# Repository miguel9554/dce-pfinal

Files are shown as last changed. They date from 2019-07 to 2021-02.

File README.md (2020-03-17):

# repositorio del proyecto final de dce - 1c2019

integrantes:

- Juan Ciafardini, 97921
- Miguel Perez Andrade, 98599
- Luis Tomás Quiroga, 96337

# 19/12/2019

## 18:00, primera medición

Medimos el punto de operación del amplificador diferencial y la fuente de corriente

* V_R10 [mV]:   571.2
* V_R8  [mV]:   383.8 
* V_R7  [mV]:   5.2
* V_R6  [mV]:   377.7
* V_R2  [mV]:   99
* V_R1  [mV]:   57.3
* V_bQ2 [mV]:   631
* V_bQ3 [mV]:   202.1

Problemas:

* Falta una vía en el emisor de Q2          -> corregido
* Un cacho de tierra no está conectado      -> conecta nada más las resistencias de la etapa de potencia, después lo conectamos
* Se rompio el contacto del capa C3         -> arreglar cuando se mida la señal

## 19:28, segunda medición

Medimos el punto de operación del amplificador diferencial y la fuente de corriente

* V_R10 [mV]:   568.1
* V_R8  [mV]:   380.7 
* V_R7  [mV]:   5.2
* V_R6  [mV]:   374.5
* V_R2  [mV]:   98.1
* V_R1  [mV]:   156.4
* V_bQ2 [mV]:   628
* V_eQ2 [V]:    -9.97
* V_bQ3 [mV]:   200.1
* V_eQ3  [V]:   -9.29

Cálculos

* I_R7  :   0.052u
* I_R6  :   3.74m
* I_R2  :   1.44m
* I_R1  :   2.3m
* I_R15 :   52u
* I_R5  :   16.67u

# 03/02/2020

## 16:40, 1ra medición

Medimos el punto de operación del amplificador diferencial y la fuente de corriente (nodos diff LT)

* V_R10 [mV]:   573.2           (J9 vs V+)
* V_R8  [mV]:   387.5           (J4 vs V+)
* V_R7  [mV]:   5.3         (entre J19 y J2)
* V_R6  [mV]:   378.4           (entre J19 y J20)
* V_R2  [mV]:   99.8            (J3 vs V-)
* V_R1  [mV]:   157.2           (J6 vs V-, entrada)
* V_bQ2 [mV]:   604.7           (J15)
* V_eQ2 [V]:    1.175
* V_bQ3 [mV]:   200.8
* V_eQ3  [V]:   0.806

Soldamos los conectores de Q2 y Q4 que estaban desconectados, medimos de vuelta

## 17:37, 2da medición

Medimos el punto de operación del amplificador diferencial y la fuente de corriente (nodos diff LT)

* V_R10 [mV]:   571.1               (J9 vs V+)
* V_R8  [mV]:   383.5               (J4 vs V+)
* V_R7  [mV]:   190.8               (entre J19 y J2)
* V_R6  [mV]:   191.1               (entre J19 y J20)
* V_R2  [mV]:   130.9               (J3 vs V-)
* V_R1  [mV]:   129.0               (J6 vs V-, entrada)
* V_bQ2 [mV]:   102.3               (J15)
* V_eQ2 [mV]:   696.0
* V_bQ3 [mV]:   103.0
* V_eQ3 [mV]:   696.0

Soldamos R10 a V+, y el capa de filtrado de la fuente de corriente (C7 en Kicad) a V+

## 18:32, 3ra medición

Medimos el punto de operación del amplificador diferencial y la fuente de corriente (nodos diff LT)

* V_R10 [mV]:   563.5               (J9 vs V+)
* V_R8  [mV]:   538.5               (J4 vs V+)
* V_R7  [mV]:   267.4               (entre J19 y J2)
* V_R6  [mV]:   267.3               (entre J19 y J20)
* V_R2  [mV]:   183.0               (J3 vs V-)
* V_R1  [mV]:   180.0               (J6 vs V-, entrada)
* V_bQ2 [mV]:   141.8               (J15)
* V_eQ2 [mV]:   742.0
* V_bQ3 [mV]:   143.2
* V_eQ3 [mV]:   742.0

Cambiamos la resistencia R8 por una de 47, era de 100 y estaba dando mal por eso

## 19:14, 4ta medición

Medimos el punto de operación del amplificador diferencial y la fuente de corriente (nodos diff LT)

* V_R10 [mV]:   561.6               (J9 vs V+)
* V_R8  [mV]:   497.8               (J4 vs V+)
* V_R7  [mV]:   528.9               (entre J19 y J2)
* V_R6  [mV]:   529.4               (entre J19 y J20)
* V_R2  [mV]:   361.8               (J3 vs V-)
* V_R1  [mV]:   357.5               (J6 vs V-, entrada)
* V_bQ2 [mV]:   274.3               (J15)
* V_eQ2 [mV]:   880.0
* V_bQ3 [mV]:   275.5
* V_eQ3 [mV]:   879.0

Medimos con 30V GUARDA CON LAS CHISPAS

## 19:21, 5ta medición

Medimos el punto de operación del amplificador diferencial y la fuente de corriente (nodos diff LT)

* V_R10 [mV]:   582.7               (J9 vs V+)
* V_R8  [mV]:   548.5               (J4 vs V+)
* V_R7  [mV]:   583.3               (entre J19 y J2)
* V_R6  [mV]:   581.7               (entre J19 y J20)
* V_R2  [mV]:   399.1               (J3 vs V-)
* V_R1  [mV]:   392.9               (J6 vs V-, entrada)
* V_bQ2 [mV]:   245.1               (J15)
* V_eQ2 [mV]:   795.0
* V_bQ3 [mV]:   245.7
* V_eQ3 [mV]:   796.0

# 04/02/2020

## 17:42, 1ra medición

Medimos después de soldar el vas sin conectarlo todavía, para ver que todo siga andando

* V_R10 [mV]:   564.2           (J9 vs V+)
* V_R8  [mV]:   497.2           (J4 vs V+)
* V_R7  [mV]:   527.4           (entre J19 y J2)
* V_R6  [mV]:   527.1           (entre J19 y J20)
* V_R2  [mV]:   360.7           (J3 vs V-)
* V_R1  [mV]:   356.0           (J6 vs V-, entrada)
* V_bQ2 [mV]:   274.0           (J15)
* V_eQ2 [mV]:   883.0
* V_bQ3 [mV]:   276.3
* V_eQ3 [mV]:   883.0

## 18:00, 2da medición

Medimos con todo conectado (vas)

* V_R10 [mV]:   32          (J9 vs V+)
* V_R8  [mV]:   58.9            (J4 vs V+)
* V_R7  [mV]:   93.9        (entre J19 y J2)
* V_R6  [mV]:   30.4            (entre J19 y J20)
* V_R2  [mV]:   21.8            (J3 vs V-)
* V_R1  [mV]:   20.3            (J6 vs V-, entrada)
* V_bQ2 [mV]:   7670            (J15)
* V_eQ2 [mV]:   8390
* V_bQ3 [mV]:   7860
* V_eQ3 [mV]:   8460
* V_Vas [mv]:   7980

## 18:26, 3ra medición

Arreglamos la pista que se había cortado (la que iba entre la salida del vas y el diodo) y dimos vuelta los diodos

* V_R10 [mV]:   32          (J9 vs V+)
* V_R8  [mV]:   58.9            (J4 vs V+)
* V_R7  [mV]:   93.9        (entre J19 y J2)
* V_R6  [mV]:   30.4            (entre J19 y J20)
* V_R2  [mV]:   21.8            (J3 vs V-)
* V_R1  [mV]:   20.3            (J6 vs V-, entrada)
* V_bQ2 [mV]:   7670            (J15)
* V_eQ2 [mV]:   8390
* V_bQ3 [mV]:   7860
* V_eQ3 [mV]:   8460
* V_Vas [mv]:   7980

## 19:09, 4ta medición

No estaba conectado el jumper que conectaba la salida del diferencial con el buffer, lo soldamos. También soldamos una pata del transitor del mult de vbe.

* Vcc   [V]:    10   |  30
* V_R10 [mV]:   560.2|580.0             (J9 vs V+)
* V_R8  [mV]:   502.9|567.0             (J4 vs V+)
* V_R7  [mV]:   534.4|602.0             (entre J19 y J2)
* V_R6  [mV]:   536.3|607.5             (entre J19 y J20)
* V_R2  [mV]:   367.1|413.2             (J3 vs V-)
* V_R1  [mV]:   364.9|411.3             (J6 vs V-, entrada)
* V_bQ2 [mV]:   273.6|248.3             (J15)
* V_eQ2 [mV]:   879.0|794.0
* V_bQ3 [mV]:   268.4|237.7
* V_eQ3 [mV]:   875.0|790.0
* V_Vas [mv]:   016.0|019.0

# 06/02/2020

## 17:21, 1ra medición

Alimentación de 27.6 V

* V_R10 [mV]:   590.8           (J9 vs V+)
* V_R8  [mV]:   599.0           (J4 vs V+)
* V_R7  [mV]:   124.3           (entre J19 y J2)
* V_R6  [mV]:   1042.0          (entre J19 y J20)
* V_R2  [mV]:   446.0           (J3 vs V-)
* V_R1  [mV]:   524.0           (J6 vs V-, entrada)
* V_bQ2 [mV]:   15023.0         (J15)
* V_eQ2 [mV]:   24040.0
* V_bQ3 [mV]:   22038.0
* V_eQ3 [mV]:   23075.0

## 18:23, 2da medición

Medición con la realimentación conectada, no está funcionando

* V_R10 [mV]:   603.5           (J9 vs V+)
* V_R8  [mV]:   600.0           (J4 vs V+)
* V_R7  [mV]:   126.2           (entre J19 y J2)
* V_R6  [mV]:   1430.0          (entre J19 y J20)
* V_R2  [mV]:   448.0           (J3 vs V-)
* V_R1  [mV]:   530.0           (J6 vs V-, entrada)
* V_bQ2 [mV]:   15300.0         (J15)
* V_eQ2 [mV]:   24640.0
* V_bQ3 [mV]:   22440.0
* V_eQ3 [mV]:   24000.0

## 18:31, 3ra medición

Medición solo del diferencial

* V_R10 [mV]:   600.8           (J9 vs V+)
* V_R8  [mV]:   558.0           (J4 vs V+)
* V_R7  [mV]:   569.5           (entre J19 y J2)
* V_R6  [mV]:   617.0           (entre J19 y J20)
* V_R2  [mV]:   404.6           (J3 vs V-)
* V_R1  [mV]:   411.0           (J6 vs V-, entrada)
* V_bQ2 [mV]:   332.0           (J15)
* V_eQ2 [mV]:   898.7
* V_bQ3 [mV]:   281.0
* V_eQ3 [mV]:   846.0

# 10/02/2020

# 16:29, 1ra medición

Como no anduvo una mierda la semana pasada, vamos a medir todos los transistores para ver si alguno está roto. Nos basamos en lo explicado en https://www.fluke.com/en-us/learn/best-practices/test-tools-basics/digital-multimeters/how-to-test-diodes-using-a-digital-multimeter y https://electronics.stackexchange.com/a/83752. Los nombres de los transistores van a estar referidos al esquemático de kicad. Todas las mediciones se hacen con un multimetro en modo diodo

* Q3
    * VbeD [mv]: 646
    * VbeI [mv]: 1800
    * VbcD [mv]: 641
    * VbcI [mv]: 0L
    * Vec [mv]: 0L
    * Vce [mv]: 1343
* Q1
    * VbeD [mv]: 649
    * VbeI [mv]: 0L
    * VbcD [mv]: 645
    * VbcI [mv]: 0L
    * Vec [mv]: 700
    * Vce [mv]: 0L
* Q5
    * VbeD [mv]: 642
    * VbeI [mv]: 0L
    * VbcD [mv]: 639
    * VbcI [mv]: 0L
    * Vec [mv]: 0L
    * Vce [mv]: 0L
* Q2
    * VbeD [mv]: 649
    * VbeI [mv]: 0L
    * VbcD [mv]: 648
    * VbcI [mv]: 0L
    * Vec [mv]: 0L
    * Vce [mv]: 1300

* Q2 (tiene cortado base y colector)
    * VbeD [mv]: 600
    * VbeI [mv]: 0L
    * VbcD [mv]: -
    * VbcI [mv]: -
    * Vec [mv]: -
    * Vce [mv]: -

* Q7
    * VbeD [mv]: 656
    * VbeI [mv]: 0L
    * VbcD [mv]: 651
    * VbcI [mv]: 0L
    * Vec [mv]: 710
    * Vce [mv]: 710

* Q10
    * VbeD [mv]: 655
    * VbeI [mv]: 1415
    * VbcD [mv]: 652
    * VbcI [mv]: 0L
    * Vec [mv]: 911
    * Vce [mv]: 0L

* Q8
    * VbeD [mv]: 645
    * VbeI [mv]: 844
    * VbcD [mv]: 640
    * VbcI [mv]: 0L
    * Vec [mv]: 861
    * Vce [mv]: 1715

* Q6
    * VbeD [mv]: 1403
    * VbeI [mv]: 1430
    * VbcD [mv]: 1722
    * VbcI [mv]: 1723
    * Vec [mv]: 700
    * Vce [mv]: 888

* Q9
    * VbeD [mv]: 589
    * VbeI [mv]: 1040
    * VbcD [mv]: 583
    * VbcI [mv]: 1695
    * Vec [mv]: 1008
    * Vce [mv]: 1799

Medimos un mje340 y un mpsa06 buenos, sin usar

* MJE340
    * VbeD [mv]: 618
    * VbeI [mv]: 0L
    * VbcD [mv]: 613
    * VbcI [mv]: 0L
    * Vec [mv]: 0L
    * Vce [mv]: 0L

* MPSA06
    * VbeD [mv]: 668
    * VbeI [mv]: 0L
    * VbcD [mv]: 665
    * VbcI [mv]: 0L
    * Vec [mv]: 0L
    * Vce [mv]: 0L

Con estás ultimas mediciones, parece que están todos rotos salvo Q5. Es posible que el circuito externo que tiene cada dispositivo esté alterando las mediciones, y los resultados no sean correctos. Vamos a sacar los transistores y medirlos solos para comprobar.

Mediciones con los transistores desoldados:

* Q9
    * VbeD [mv]: 624
    * VbeI [mv]: 0L
    * VbcD [mv]: 620
    * VbcI [mv]: 0L
    * Vec [mv]: 0L
    * Vce [mv]: 0L

* Q3
    * VbeD [mv]: 646
    * VbeI [mv]: 0L
    * VbcD [mv]: 643
    * VbcI [mv]: 0L
    * Vec [mv]: 0L
    * Vce [mv]: 0L

* Q10
    * VbeD [mv]: 661
    * VbeI [mv]: 0L
    * VbcD [mv]: 630
    * VbcI [mv]: 0L
    * Vec [mv]: 0L
    * Vce [mv]: 0L

* Q7 (parece estar cagado, ver la potencia)
    * VbeD [mv]: 653
    * VbeI [mv]: 0L
    * VbcD [mv]: 650
    * VbcI [mv]: 0L
    * Vec [mv]: \~710
    * Vce [mv]: \~710

Con Q9 comprobamos la medición volviendo a soldarlo, y dio mal igual que antes. Esto nos da la pauta de que el circuito externo a cada dispositivo esta perturbando la medición cuando medimos al dispositivo conectado al resto del circuito.

Q7 parece estar cagado, la medición del transistor solo da mal (no hay abierto entre colector y emisor). En base a esto y a que el circuito diferencial estaba funcionando sin la etapa VAS, suponemos que cambiar este transistor va a solucionar el problema.

## 18:52, 2da medición

Medimos con Q7 reemplazado, el circuito diferencial con el vas (medimos rápidamente la fuente de corriente y el diferencial antes de esto y daba bien)
Se quemó la resistencia R4 (en PCB)

* V_R10 [mV]:   573.3           (J9 vs V+)
* V_R8  [mV]:   536.6           (J4 vs V+)
* V_R7  [mV]:   081.5           (entre J19 y J2)
* V_R6  [mV]:   1018.0           (entre J19 y J20)
* V_R2  [mV]:   384.0           (J3 vs V-)
* V_R1  [mV]:   430.5           (J6 vs V-, entrada)
* V_bQ2 [mV]:   -15150          (J15)
* V_eQ2 [mV]:   -18160
* V_bQ3 [mV]:   -14260
* V_eQ3 [mV]:   -19320
* V_oVAS[mV]:   -18750

## 19:07, 2da medición

Medimos solo el diferencial para comprobar que siga andando

* V_R10 [mV]:   599.0           (J9 vs V+)
* V_R8  [mV]:   541.9           (J4 vs V+)
* V_R7  [mV]:   530.8           (entre J19 y J2)
* V_R6  [mV]:   577.9           (entre J19 y J20)
* V_R2  [mV]:   373.6           (J3 vs V-)
* V_R1  [mV]:   378.4           (J6 vs V-, entrada)
* V_bQ2 [mV]:   319.7          (J15)
* V_eQ2 [mV]:   886.6
* V_bQ3 [mV]:   270.4
* V_eQ3 [mV]:   843.4

Vamos a medir los transistores del par diferencial y su carga activa

* Q1
    * VbeD [mv]: 647
    * VbeI [mv]: 0L
    * VbcD [mv]: 643.8
    * VbcI [mv]: 0L
    * Vec [mv]: 0L
    * Vce [mv]: 0L

* Q5
    * VbeD [mv]: 640.0
    * VbeI [mv]: 0L
    * VbcD [mv]: 643.4
    * VbcI [mv]: 0L
    * Vec [mv]: 0L
    * Vce [mv]: 0L

* Q2
    * VbeD [mv]: 668.0
    * VbeI [mv]: 0L
    * VbcD [mv]: 599.5
    * VbcI [mv]: 0L
    * Vec [mv]: 0L
    * Vce [mv]: 0L

* Q4
    * VbeD [mv]: 600.0
    * VbeI [mv]: 0L
    * VbcD [mv]: 666.0
    * VbcI [mv]: 0L
    * Vec [mv]: 0L
    * Vce [mv]: 0L

* Q6
    * VbeD [mv]: 582.5
    * VbeI [mv]: 0L
    * VbcD [mv]: 643.5
    * VbcI [mv]: 0L
    * Vec [mv]: 0L
    * Vce [mv]: 0L

* Q8
    * VbeD [mv]: 642.5
    * VbeI [mv]: 0L
    * VbcD [mv]: 640.0
    * VbcI [mv]: 0L
    * Vec [mv]: 0L
    * Vce [mv]: 0L

##  20:06, 3ra medición

Probamos todos los transistores y parecen estar bien. Soldamos la pistas de la base de Q2 y el colector Q6 (fuente de corriente) que no estaban unidas. Medimos de vuelta

* V_R10 [mV]:   571.5           (J9 vs V+)
* V_R8  [mV]:   558           (J4 vs V+)
* V_R7  [mV]:   85.8           (entre J19 y J2)
* V_R6  [mV]:   10892           (entre J19 y J20)
* V_R2  [mV]:   411.4           (J3 vs V-)
* V_R1  [mV]:   460           (J6 vs V-, entrada)
* V_bQ2 [mV]:   -1513          (J15)
* V_eQ2 [mV]:   -18.33
* V_bQ3 [mV]:   -14092
* V_eQ3 [mV]:   -19.53
* V_oVAS[mV]:   -18507

Las fuentes daban 30 mili cada una
Medimos el diferencial primero y estaba balanceado

#   11/02/2020

##  18:16, 1ra medición

Medición sin realizar ningún cambio.

* V_R10 [mV]:   603.4           (J9 vs V+)
* V_R8  [mV]:   564.0           (J4 vs V+)
* V_R7  [mV]:   576.7           (entre J19 y J2)
* V_R6  [mV]:   581.8           (entre J19 y J20)
* V_R2  [mV]:   395.5           (J3 vs V-)
* V_R1  [mV]:   393.8           (J6 vs V-, entrada)
* V_bQ2 [mV]:   359.7          (J15)
* V_eQ2 [mV]:   938.0
* V_bQ3 [mV]:   359.2
* V_eQ3 [mV]:   932.0
* V_oVAS[mV]:   075.4

El problema era el potenciómetro del multiplicador de vbe que estaba flojo.

##  Modificaciones
* Sacamos el capacitor de 1uF entre -VCC y GND porque estaba cortada la pista de -VCC en ese nodo.
* Cambiamos el potenciómetro, pareciera seguir habiendo algún problema relacionado a su conexión.

# 13/02/2020

Empezamos viendo si el pote está bien soldado, si hay la resistencia que tiene que haber entre las pistas. Lo resoldamos y parece dar bien

##  16:55, 1ra medición

Medición después de soldar bien el pote.

* V_R10 [mV]:   605.7           (J9 vs V+)
* V_R8  [mV]:   569.1           (J4 vs V+)
* V_R7  [mV]:   580.5           (entre J19 y J2)
* V_R6  [mV]:   585.9           (entre J19 y J20)
* V_R2  [mV]:   397.3           (J3 vs V-)
* V_R1  [mV]:   396.0           (J6 vs V-, entrada)
* V_bQ2 [mV]:   367.4          (J15)
* V_eQ2 [mV]:   946.0
* V_bQ3 [mV]:   365.9
* V_eQ3 [mV]:   941.0
* V_oVAS[mV]:   57.0

Da bien! Parece ser que el problema era el pote.

Ahora vamos a medir la ganancia con fin=1k.
Vpp entrada [mV]    Vpp salida [V]  Ganancia
200     5.4     27
300     8.48    28.26
400     11.12   27.8
500     13.8    27.6
600     16.20   27
800     21.2    26.5
1000    26.40   26.4
1200    31.8    26.5
1500    39.20   26.13
1530    40      26.14

Ahora vamos a medir la ganancia con fin=10k (hay que recalcular la ganancia).
Vpp entrada [mV]    Vpp salida [V]  Ganancia
200     5.12    27
300     8.48    28.26
400     11.04   27.8
500     13.44   27.6
600     16.00   27
800     21.2    26.5
1000    26.40   26.4
1200    31.8    26.5
1500    40      26.13
1530    40      26.14

Medimos la salida con 1 Vpp a la entrada, y variando la frecuencia.
f [Hz]  Vpp salida [V]
20  26.8
200 26.8
2k  26.6
20k 26.8
50k 26.8
200k    26

Da joya la baja potencia, arrancamos a soldar la parte de potencia.

Cosas que hay que comprar:
* Disipadores
* Pasta térmica
* Diodos 1N4148
* Capacitores de 1u y 50V
* Resistencia de 50W

Cosas para ver:
* Ver porque que en el esquemático hay 1N4148 cuando debería haber LM385
* Soldar todas las pistas de los componentes de potencia cuando 
* Cambiar C7 que está quemado, y volver a poner C8

# 17/02/2020

La idea de hoy era soldar toda la etapa de potencia y montar los disipadores. El disipador de los transistores de potencia y el multiplicador de vbe no se pudo montar, asi que solo soldamos la etapa de potencia. Medimos continuidad y parece estar todo bien conectado. Solo falta soldar las pistas de arriba de los transistores que van al disipador. No lo hicimos para que tengan mas movilidad cuando pongamos el disipador. Mañana hay que comprar
* Disipador ZD27-10, de 10 cm de largo
* Tornillos y mica

# 21/02/2020

Ya está todo soldado y armado, vamos a medir la polarización para todo el circuito

## 1ra medición, 18:26

* V_R10 [mV]:   603
* V_R8  [mV]:   572
* V_R7  [mV]:   579.5
* V_R6  [mV]:   581.7
* V_R2  [mV]:
* V_R1  [mV]:
* V_bQ2 [mV]:
* V_eQ2 [mV]:
* V_bQ3 [mV]:
* V_eQ3 [mV]:
* V_oVAS[mV]:
* V_bQ11[mV]:
* V_bQ16[mV]:
* V_bQ12[mV]:
* V_bQ15[mV]:
* V_R18 [mV]:
* V_R19 [mV]:

Tratabamos de medir y cuando mediamos algunos nodos (VoVas, VR7, VR6) la fuente empezaba a entregar corrientes erróneas. Vamos a medir con un osciloscopio enganchado en VoVas para ver si hay oscilaciones

Encontramos una oscilación, chequeamos en la simulación y encontramos que con el capa de compensación de 100p, el circuito está inestable. Lo reemplazamos por uno de 470p que da estable. REEMPLAZAR EN EL LTSPICE EL CAPA DE 100P POR ESTE DE 470P

Hablamos con Fede
- Tratar de que haya aprox 100 mA en la rama de salida, ahora hay 500mA. Probamos llevando la resistencia del mult de vbe 1.5K, daba bien la THD y aprox 100 mA a la salida, ver si cambiamos el pote por uno de 500.
- SIEMPRE limitar la corriente de las fuentes antes de medir. Para esto, llevar a cero la tensión y el límite de corriente, cortocircuitar la fuente e incrementar el límite de corriente hasta llegar a la limitación deseada.

Cosas para cambiar en las simulaciones
- Poner un capacitor de 470p
- Ver la resistencia del mult de vbe, en 1.5k aparentemente da bien

## 2da medición, 19:58

Medimos después de reemmplazar el capa de 100p por uno de 470p

* V_R10 [mV]:   610
* V_R8  [mV]:   567
* V_R7  [mV]:   577
* V_R6  [mV]:   584
* V_R2  [mV]:   397.4
* V_R1  [mV]:   396.9
* V_bQ2 [mV]:   370.2
* V_eQ2 [mV]:   954
* V_bQ3 [mV]:   369.2
* V_eQ3 [mV]:   948
* V_oVAS[mV]:   -1914

# 28/02/20

Vamos a medir la polarización de la etapa de potencia

## 1ra medición, 19:54

Medimos 

* V_R10 [mV]: 599 
* V_R8  [mV]: 568
* V_R7  [mV]: 539
* V_R6  [mV]: 583
* V_R2  [mV]: 396
* V_R1  [mV]: 394
* V_bQ2 [mV]: 356
* V_eQ2 [mV]: 930
* V_bQ3 [mV]: 356
* V_eQ3 [mV]: 926
* V_oVAS[mV]: -1800
* V_bQ11[mV]: 1060
* V_bQ16[mV]: 984
* V_R20 [mV]: 848
* V_R18 [mV]: 0
* V_R19 [mV]: 0
* V_o   [mV]: 57

## 2da medición, 20:25

Soldamos el pin de alimentación de V+, estaba desconectado. Medimos y NO DABA, no medimos todos los nodos por paja

* V_R10 [mV]: 
* V_R8  [mV]: 
* V_R7  [mV]: 
* V_R6  [mV]: 583
* V_R2  [mV]: 396
* V_R1  [mV]: 394
* V_bQ2 [mV]: 356
* V_eQ2 [mV]: 930
* V_bQ3 [mV]: 356
* V_eQ3 [mV]: 926
* V_oVAS[mV]: -1800
* V_bQ11[mV]: 1060
* V_bQ16[mV]: 984
* V_R20 [mV]: 848
* V_R18 [mV]: 0
* V_R19 [mV]: 
* V_o   [mV]: 56

## 3ra medición, 20:50

Soldamos bien el colector de Q17 que no estaba haciendo contacto con la pista. NO DIO

## 4ta medición, 21:08

Soldamos bien el emisor de Q18 que no estaba haciendo contacto con la resistencia R22.

driver arriba
23.96
24.4

driver abajo
24.03
24.4

transistor exterior arriba
9.99
10.2

Vimos que llevando el pote a 0, teníamos 0.05mV sobre las resistencias de emisor, y si lo tirabamos a 200, había 0V. Hay que bajar la resistencia.

# 02/03/202

Modificamos la resistencia del multiplicador de vbe a 1.2 k más el preset. Procedemos a medir la polarización.

# Primera medición, 14:55

Sin conectar las fuentes internas

* V_R10 [mV]: 612             (J9 vs V+)
* V_R8  [mV]: 572             (J4 vs V+)
* V_R7  [mV]: 587             (entre J19 y J2)
* V_R6  [mV]: 589             (entre J19 y J20)
* V_R2  [mV]: 403             (J3 vs V-)
* V_R1  [mV]: 402             (J6 vs V-, entrada)
* V_bQ2 [mV]: 361            (J15)
* V_eQ2 [mV]: 938  
* V_bQ3 [mV]: 360  
* V_eQ3 [mV]: 934  
* V_oVAS[mV]: -1980
* V_bQ11[mV]: 
* V_bQ16[mV]: 
* V_R20 [mV]: 
* V_R18 [mV]: 
* V_R19 [mV]: 
* V_o   [mV]: 57

Corriente de las fuentes entre 40 y 50 mA.

# Segunda medición, 15:30

Conectadas las fuentes internas

* V_R10 [mV]: 601             (J9 vs V+)
* V_R8  [mV]: 576             (J4 vs V+)
* V_R7  [mV]: 584             (entre J19 y J2)
* V_R6  [mV]: 588             (entre J19 y J5)
* V_R2  [mV]: 400             (J3 vs V-)
* V_R1  [mV]: 398             (J6 vs V-, entrada)
* V_bQ2 [mV]: 354            (J15)
* V_eQ2 [mV]: 926  
* V_bQ3 [mV]: 352  
* V_eQ3 [mV]: 923  
* V_oVAS[mV]: -2000
* V_bQ11[mV]: 1192
* V_bQ16[mV]: 1295
* V_R20 [mV]: 1278
* V_R18 [mV]: 5				(50 mA)
* V_R19 [mV]: 5
* V_o   [mV]: 55

# Tercera medición, 15:56

Cambiamos la resistencia del preset de 40 ohm a 120 ohm para bajar la corrien te en la rama de salida.

* V_R10 [mV]: 605
* V_R8  [mV]: 574
* V_R7  [mV]: 585
* V_R6  [mV]: 590
* V_R2  [mV]: 401
* V_R1  [mV]: 399
* V_bQ2 [mV]: 356
* V_eQ2 [mV]: 931 
* V_bQ3 [mV]: 356  
* V_eQ3 [mV]: 926
* V_oVAS[mV]: -1970
* V_bQ11[mV]: 1249
* V_bQ16[mV]: 1140
* V_R20 [mV]: 1278
* V_R18 [mV]: 0.92				(9.2 mA)
* V_R19 [mV]: 0.92
* V_o   [mV]: 52

# Cuarta medición, 17:13

Se produjo un corto al medir señal.

* V_R10 [mV]: 608
* V_R8  [mV]: 573
* V_R7  [mV]: 585
* V_R6  [mV]: 590
* V_R2  [mV]: 401
* V_R1  [mV]: 399
* V_bQ2 [mV]: 362
* V_eQ2 [mV]: 946 
* V_bQ3 [mV]: 362  
* V_eQ3 [mV]: 940
* V_oVAS[mV]: -1950
* V_bQ11[mV]: 1290
* V_bQ16[mV]: 1129
* V_R20 [mV]: 1190
* V_R18 [mV]: 0.27				(2.5 mA)
* V_R19 [mV]: 0.25
* V_o   [mV]: 54

Bajó la corriente de salida. Probablemente se corrió el potenciómetro.
Se solucionó acomodando algunos contactos de las fuentes de alimentación.

El circuito presenta una senoidal de 7.6 MHz y 1.2 Vpp a la salida en ausencia
de señal de entrada. Al agregarse la señal de entrada se suma a la salida con poca amplificación.
Probar cambiar capacitor de compensación.

# 03/03/202

Soldamos dos capacitores de 220 pF entre base y colector de los transistores externos del driver.

# Primera medición, 16:23

* V_R10 [mV]: 604
* V_R8  [mV]: 570
* V_R7  [mV]: 581
* V_R6  [mV]: 587
* V_R2  [mV]: 399
* V_R1  [mV]: 397
* V_bQ2 [mV]: 355
* V_eQ2 [mV]: 932  
* V_bQ3 [mV]: 353 
* V_eQ3 [mV]: 928  
* V_oVAS[mV]: -1980
* V_bQ11[mV]: 1249
* V_bQ16[mV]: 1146
* V_R20 [mV]: 1190
* V_R18 [mV]: 0.90		(9 mA)
* V_R19 [mV]: 0.93
* V_o   [mV]: 48

La ganancia está muy afectada para casi todas las frecuencias, ya en la salida del VAS.
La mayor ganancia encontrada es 3, para 1 MHz.
La cuadrada muestra que no està sobrecompensado.

# 05/03/2020

Medimos primero sin cambiar nada

* V_R10 [mV]: 601
* V_R8  [mV]: 574
* V_R7  [mV]: 584
* V_R6  [mV]: 587
* V_R2  [mV]: 400
* V_R1  [mV]: 399
* V_bQ2 [mV]: 350
* V_eQ2 [mV]: 924  
* V_bQ3 [mV]: 350 
* V_eQ3 [mV]: 919  
* V_oVAS[mV]: -1936
* V_bQ11[mV]: 1277
* V_bQ16[mV]: 1104
* V_R20 [mV]: 1177
* V_R18 [mV]: 0.80      (8 mA)
* V_R19 [mV]: 0.90
* V_o   [mV]: 48

Medimos para verificar que esté igual que al inicio

* V_R10 [mV]: 600
* V_R8  [mV]: 571
* V_R7  [mV]: 582
* V_R6  [mV]: 587
* V_R2  [mV]: 398
* V_R1  [mV]: 397
* V_bQ2 [mV]: 345
* V_eQ2 [mV]: 919  
* V_bQ3 [mV]: 346 
* V_eQ3 [mV]: 913  
* V_oVAS[mV]: -1968
* V_bQ11[mV]: 1241
* V_bQ16[mV]: 1137
* V_R20 [mV]: 1181
* V_R18 [mV]: 1.80      (18 mA)
* V_R19 [mV]: 1.70
* V_o   [mV]: 45

Si se toca con metal Vin, Vout, R18 o R19, VbQ2: aparece la oscilación de 7 Mhz 2 Vpp a la salida.
Si se toca VbQ3: la tensión aumenta indefinidamente en amplitud (a veces).

# 06/03/2020

Medimos después de agergar un capa de 220 pF en paralelo con el que ya pusimos en Q12

* V_R10 [mV]: 602
* V_R8  [mV]: 573
* V_R7  [mV]: 584
* V_R6  [mV]: 587
* V_R2  [mV]: 399
* V_R1  [mV]: 397
* V_bQ2 [mV]: 366
* V_eQ2 [mV]: 957  
* V_bQ3 [mV]: 362 
* V_eQ3 [mV]: 953  
* V_oVAS[mV]: -1987
* V_bQ11[mV]: 1243
* V_bQ16[mV]: -1151
* V_R20 [mV]: 1185
* V_R18 [mV]: 0.8      (8 mA)
* V_R19 [mV]: 0.8
* V_o   [mV]: 43

Arreglamos el capa de 1000 uF que estaba mal soldado. El problema era que como no hacía contacto, teníamos realimentación unitaria.

Le soldamos a cada driver un capacitor extra en paralelo. Quedó cada uno con dos capas de 220 pF.

La frecuencia de corte inferior estaba en aproximadamente 25 Hz.

La ganancia estaba dando aprox 20. Para frecuencias mas altas se va a 25.

# 09/03/2020

Capacitor 440 pF en el driver clase C del semiciclo negativo, desconectado en el positivo.
Soldamos el segundo capacitor de filtrado de fuente (para -VCC) de 1000 uF.
Sin carga.

## Resultados 17:34
* Ruido de 50 Hz 280 mVpp
* Con las fuentes apagadas, pero conectadas, el mismo ruido prevalece con amplitud 50 mVpp

## Medición ancho de banda (entrada 100 mVpp) 18:00
* Frec      Amplitud    G
* 1 kHz:    2.70 Vpp    27
* 10 kHz:   2.64 Vpp    26.4
* 20 kHz:   2.68 Vpp    26.8
* 50 kHz:   2.46 Vpp    24.6
* 100 kHz:  2.1 Vpp     21
* 150 kHz:  1.82 Vpp    18.2
* 200 kHz:  1.58 Vpp    15.8

## Medición ancho de banda (entrada 1 Vpp) 18:05
* Frec      Amplitud    G
* 1 kHz:    26.4 Vpp    26.4
* 10 kHz:   27.0 Vpp    27.0    (sube la corriente entragada por la fuente a 80 mA)
* 100 kHz:  21.2 Vpp    21.2

Soldamos el capacitor de 440 pF en el driver clase C del semiciclo positivo.

* La amplificación sigue igual. El ruido en el semiciclo positivo parece venir de la conmutación
porque aparece al superar los 10 V.
* A partir de 1.2 Vpp de entrada satura el semicilo negativo (imagen enviada por mail).

## Medición con carga (entrada 1 kHz) 18:42
* Vin           Vout        G
* 46 mVpp:      632 mVpp    13.7
* 54 mVpp:      920 mVpp    17.0
* 100 mVpp:     A partir de esta tensión aparece un ruido en el cruce por cer
en la entrada y se amplifica a la salida.

Había un problema de masas, conectamos bien la masa del osciloscopio y empezamos a medir bien.

## Medición con carga (entrada 1 kHz) 19:18
* Vin           Vout        G
* 100 mVpp     2.54 Vpp    25.4
* 120 mVpp     3.24        27
* 140 mVpp     3.24        23.1
* 160 mVpp     4           25
* 200 mVpp     5.8         28

A partir de 140 mV, la señal empieza a moverse en el osciloscopio, y no es por ruido de linea. Posiblemente sea por el trigger, probar con el trigger externo conectado a la otra salida del generador de señales.

Recapitulando lo de hoy,

* Cuando la señal llega tiene 10 Vpico (el umbral de conmutación), aparece mucho ruido en el maximo del ciclo positivo
* Cuando empieza a crecer mas la señal, el ruido del ciclo positivo se achica, pero aparece una especie de rectificacion en el ciclo negativo
* Probamos con carga, y la corriente de las fuentes interiores crecía mucho más que la de las exteriores.

# 10/03/2020

Encontramos errores en la continua y volvimos a medir.

* V_R10 [mV]: 79
* V_R8  [mV]: 79
* V_R7  [mV]: 198
* V_R6  [mV]: 0
* V_R2  [mV]: 0
* V_R1  [mV]: 0
* V_bQ2 [mV]: -23000
* V_eQ2 [mV]: -24500
* V_bQ3 [mV]: -23830
* V_eQ3 [mV]: -24700
* V_oVAS[mV]: -24000
* V_bQ11[mV]: 
* V_bQ16[mV]: 
* V_R20 [mV]: 
* V_R18 [mV]: 
* V_R19 [mV]: 
* V_o   [mV]: 

Solo diferencial

* V_R10 [mV]: 600
* V_R8  [mV]: 59
* V_R7  [mV]: 199
* V_R6  [mV]: 0
* V_R2  [mV]: 0
* V_R1  [mV]: 0
* V_bQ2 [mV]: -24000
* V_bQ3 [mV]: -24000

LLegamos y medimos la ganancia. 

* V_R8  [mV]: 108
* V_R7  [mV]: 199.6
* V_R6  [mV]: 1
* V_R15 [mV]: 23850
* V_R4  [mV]: 1.7
* V_R2  [mV]: 0.7
* V_R1  [mV]: 0.8

# 12/03/2020

Unimos los planos de tierra con cables porque sospechamos que el error está en las conexiones de tierra.

Encontramos que cuando prendemos con la carga conectada solo con las fuentes exteriores, hay un transitorio de aproximadamente 5 segundos en el que la fuente positiva corta por corriente. Si es con las fuentes interiores, dura menos.

## Medición de señal sin carga (f = 1 kHz) 19:34

* Vin [mV]   Vout [V]
* 112        2.66
* 208        5.28
* 300        7.88
* 530        13.8
* 800        21.4
* 1020       26.8
* 1260       32.4
* 1460       38.0
* 1600       42.8
* 1700       45.2

# 13/03/2020

* Reemplazamos el capa de filtrado de la fuente (entre -Vcc y gnd) de 100 uF por otro de 1 uF y sigue habiendo un transitorio de aprox 3 segs. La polarización da bien.

* Vamos a mandar señal a ver si sigue amplificando bien como ayer. Dio OK

* Ahora, con las fuentes exteriores en 30 V (máxima excursión 60 V), vamos a ver hasta que amplitud de salida podemos trabajar sin distorsión (sin carga).

* Llegamos hasta una entrada de 2,16 Vpp con una salida de 50,8 Vpp. A partir de esto, empieza a haber distorsión.

* Tabla de tensiones y potencias

* Vinpp [V] Vopp [V]    Prms [W]
* 0,2       5           0,4
* 0,32      8           1
* 0,72      17,88       5
* 1         25          10
* 1,24      31          15
* 2         50.59       40
* 2,26      56.57       50

Mediciones
Vinpp [mV] Vo [V]
208 5,16
308 7,68
332 8,32
400 10,2
524 13,3
624 16,2
720 18,2

Llegamos hasta estos últimos valores, después la señal de salida empezaba a distorsionarse. Recortaba en el cilco positivo en 9,2 V, y en el negativo podía seguir creciendo pero deformada.

ERROR:

Encontramos que el diodo D3 (nomenclatura kicad) estaba conectado al emisor de Q8 en lugar del colector. Lo corregimos cortando la pista y uniendo con un cable. El kicad quedó actualizado.

Ya lo arreglamos, medimos

Mediciones
Vinpp [mV] Vo [V]
216 5,20
312 7,76
528 13,1

Estaba recortando en 6 V, desconectamos y reconectarmos la fuente y anduvo

Vinpp [mV] Vo
528 13,4
624 16,2
720 18,2

En 650 empieza a distorsionar el pico negativo empieza a distorsionarse. A partir de 750, Vcc+ deja de entregar y corriente y el ciclo positivo recorta en 9,2

Tratamos de poner 15 V en las fuentes interiores, pero las corrientes divergen, teníamos que apagarlo en alrededor de 170 mA.

Con 12 V no divergia, empezamos a subir las fuentes y hasta 14 V parecía andar bien.

Los zeners están al revés en el Douglas-Self, y en el Kicad estaban como en el Douglas Self y los dimos vuelta. Ver como van

# 16/03/2020

Hoy llegamos y tratamos de llegar a la máxima excursión de la vez pasada sin carga. Nos encontramos que a partir de aproximadamente 16 Vpp a la salida la corriente que entregaban las fuentes interiores subia demasiado, hasta 300 mA.
Empezamos a revisar y encontramos que el diodo D4 (de LTSpice) estaba al revés, lo dimos vuelta y se arreglo. Amplificamos sin carga, y llegamos a una máxima excursión de 50 Vpp, igual que la vez pasada.
Después de esto, amplificamos con carga y la parte positiva conmutaba sin problemas. La parte negativa conmuta un poco más lento, y parece tener más distorsión. Hay que medir las caidas de tensión en los caminos de Vo y los emisores de los transistores clase C hasta las  bases de los drivers de los clases C, y verificar que haya simetría. Probablemente este conmutando más tarde la etapa negativa por algo que está desbalanceado.
Llegamos a amplificar hasta 35 Vpp a la salida.

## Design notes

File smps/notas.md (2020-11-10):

Layout
* Al pote hay que acortarle la perilla a posiblemetne 16 mm (preguntar en microelectrónica)
* Los capacitores de entrada tienen el mismo footprint que los de salida, hay que definir cuales se van a usar y ver el footprint
* Los de salida se hicieron en base a la hoja de datos que se encontró, hay que verificar si es esa
* Mismo para el inductor

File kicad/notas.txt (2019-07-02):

los conectores tienen todos tamaños random, verificar eso, tambien el tamaño del capa electrolitico
agregar capacitores de bypass

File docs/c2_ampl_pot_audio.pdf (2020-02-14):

# Amplificadores de potencia de audio

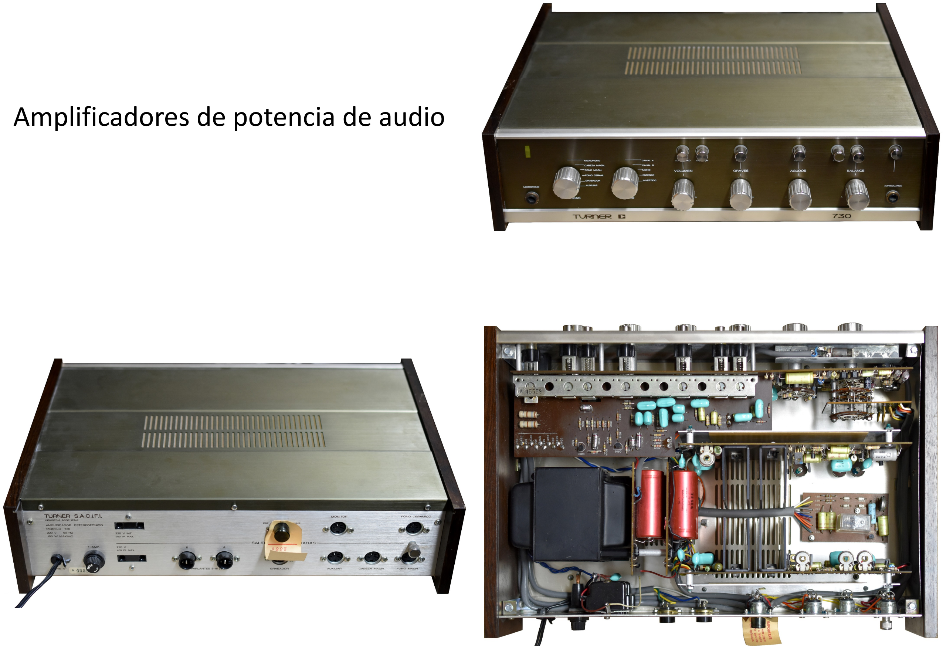
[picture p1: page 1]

## Etapa de potencia del amplificador Turner 730

n

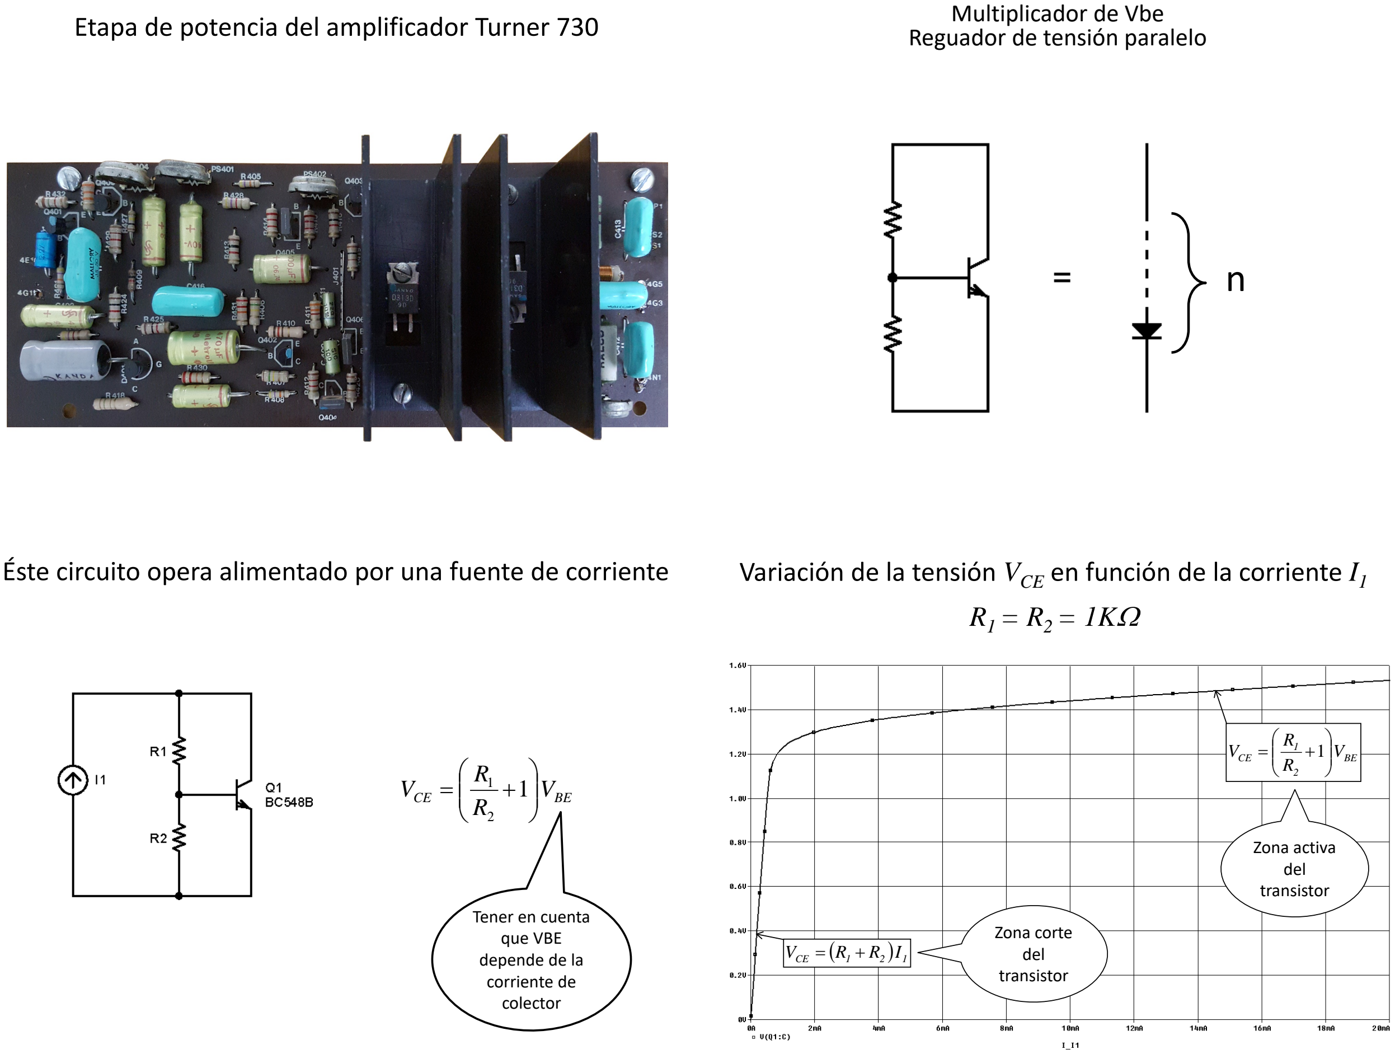
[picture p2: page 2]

## Multiplicador de Vbe

## Reguador de tensión paralelo Éste circuito opera alimentado por una fuente de corriente

CE | VBE R
R V |
= +1

2

1

Tener en cuenta
que VBE
depende de la
corriente de
colector

## Variación de la tensión VCE en función de la corriente I1

BE
2

1

CE | V
R
R V |
- = | +1
( | ) CE | 1 | 2 | 1 V = R + R I

Zona corte
del
transistor

Zona activa
del
transistor

## R1 = R2 = 1KΩ

## Variación de la tensión VCE en función de la corriente I1 y las resistencias R1 y R2

R1 = R2

## Impedancia del multiplicador

10 Ω
I

V
z | I 10mA

1

CE

1

≈
∆

∆
≅ =

## R1 = R2 = 1KΩ

## Impedancia del multiplicador como sistema realimentado

( | )
( | )( | )

8 Ω

## R gm R R R R R

| R R
a f

z Z

1

O | 1 | 1 | PI
O | O | 1
O | ≈
+

=
+

=
1 1 | // | // //

//
1
2

ICQ

= 10 mA

## gm = 0,4A/V

RPI

= 750 Ω

β = 300
VA

= 100V

RO

= 10 KΩ

f

R1

1 f = −

ZO

a

## Impedancia del multiplicador en función de la frecuencia

Circuito utilizado para análisis por simulación

## Impedancia del multiplicador en función de la frecuencia

## Impedancia del multiplicador en función de la frecuencia

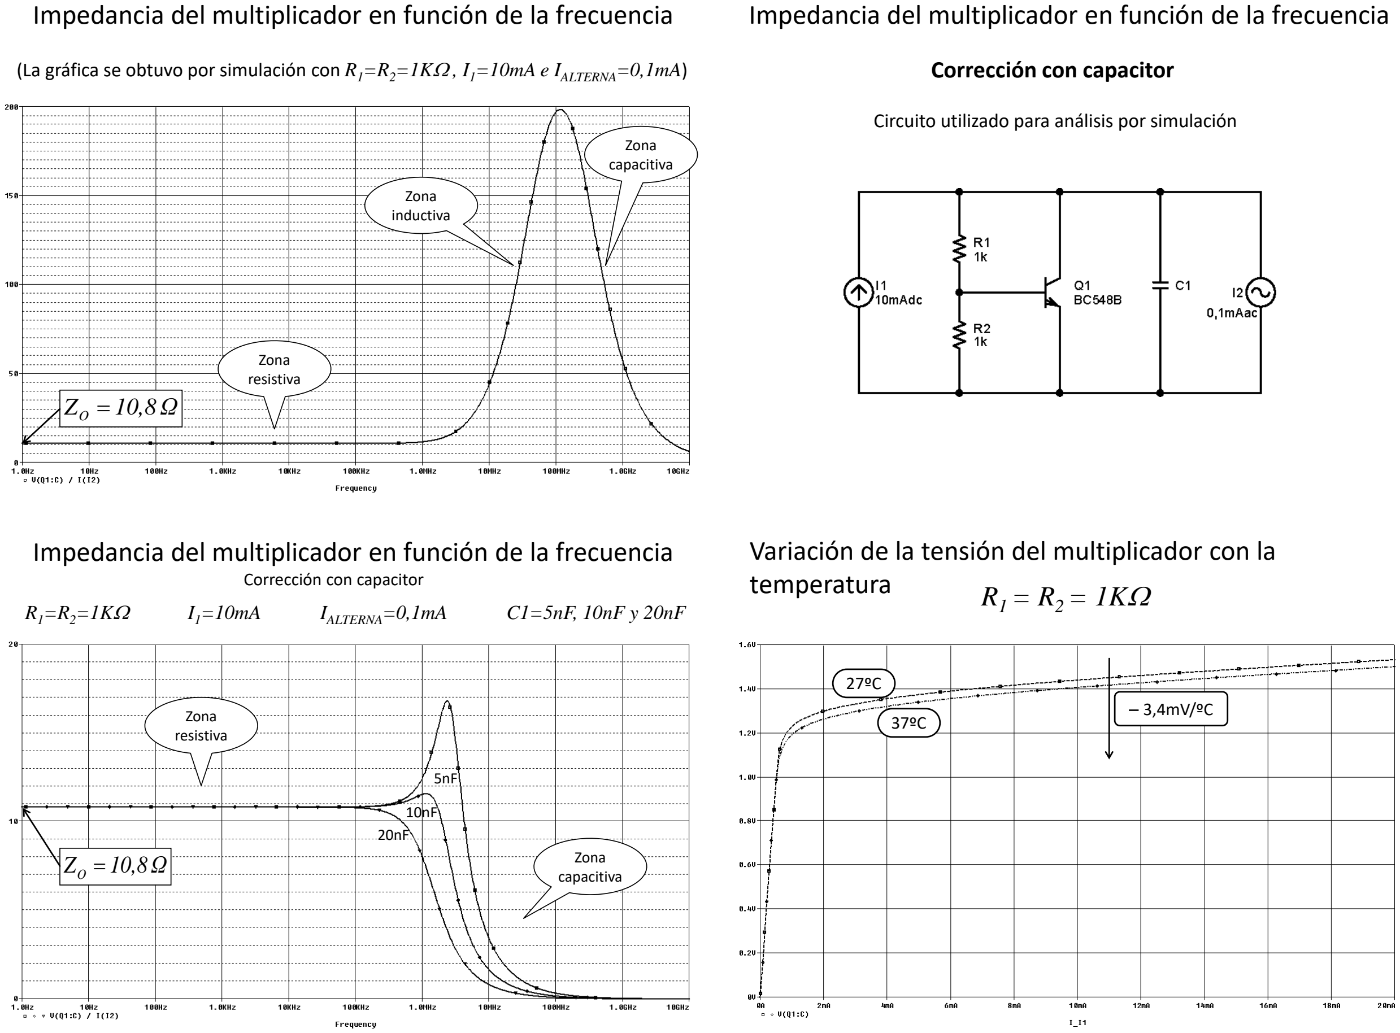
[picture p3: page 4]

ZO

= 10,8 Ω

Zona
capacitiva
Zona
inductiva

(La gráfica se obtuvo por simulación con R1=R2=1KΩ , I1=10mA e IALTERNA=0,1mA)

Zona
resistiva

Circuito utilizado para análisis por simulación

## Corrección con capacitor

## Impedancia del multiplicador en función de la frecuencia

ZO

= 10,8 Ω | Zona capacitiva
R1=R2=1KΩ | I1=10mA | IALTERNA=0,1mA | C1=5nF, 10nF y 20nF

5nF
10nF
20nF

Corrección con capacitor

Zona
resistiva

## Variación de la tensión del multiplicador con la temperatura R1 = R2 = 1KΩ

− 3,4mV/ºC 37ºC

27ºC

## Mejoramiento del multiplicador de VBE para independizarlo aún más de la corriente de polarización

BE C 3
2

1

CE | 1 V | I R
R
R V | −
≅ +

Tener en cuenta
que VBE
depende de la
corriente de
colector

## Variación de la tensión VCE en función de la corriente I1 y la resistencia de colector R3

# Estudio evolutivo de un amplificador de tensión orientado a su aplicación en amplificador de potencia de audio

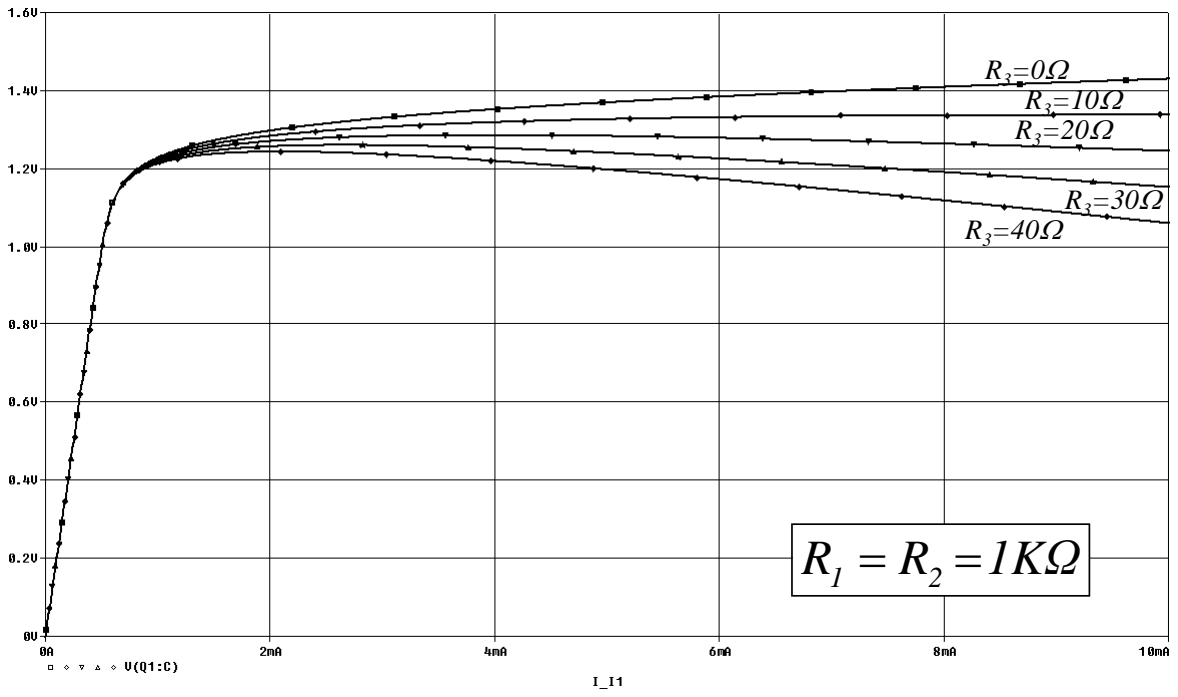
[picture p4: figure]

## Amplificador de Tensión

- Configuración típica para amplificadores operacionales o de potencia para audio y ultrasonido

- Con la técnica de realimentación se estabiliza la polarización y la ganancia de tensión. También se logra relativamente alta impedancia de entrada, baja impedancia de salida y reducida distorsión armónica.
- Se opera con doble fuente en serie (o fuente dividida) fijando el punto medio como masa, lo que permite conectar directamente la carga sin capacitor de acoplamiento.

### Amplificador de tres etapas con realimentación Polarización y realimentación

La topología de esta etapa de salida resulta en una eficiencia máxima del 25%

ETAPA DE
SALIDA
CLASE A

ETAPA DE ALTA
GANANCIA
DE TENSIÓN

ETAPA DE
COMPARACION
(O SUMADOR)

## Circuito similar al analizado en la clase de Realimentación

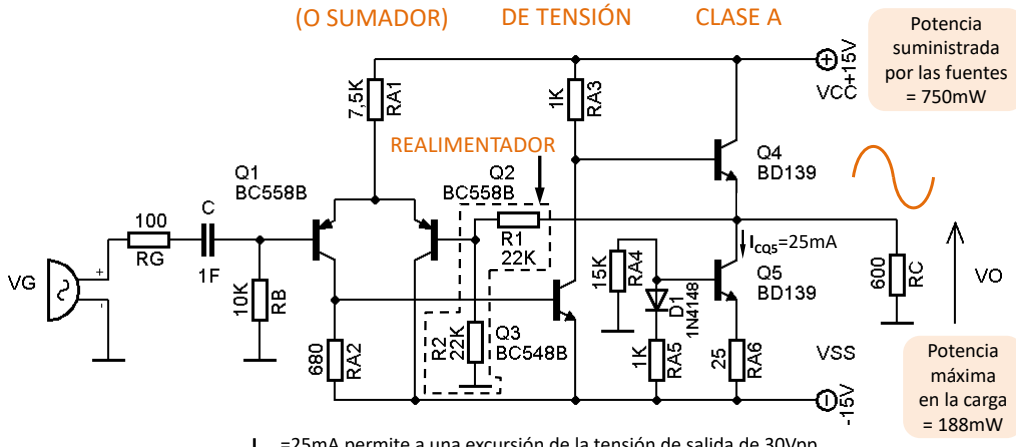
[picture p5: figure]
REALIMENTADOR; Potencia suministrada por las fuentes = 750mW; Potencia máxima en la carga = 188mW; ICQ5=25mA

ICQ5=25mA permite a una excursión de la tensión de salida de 30Vpp

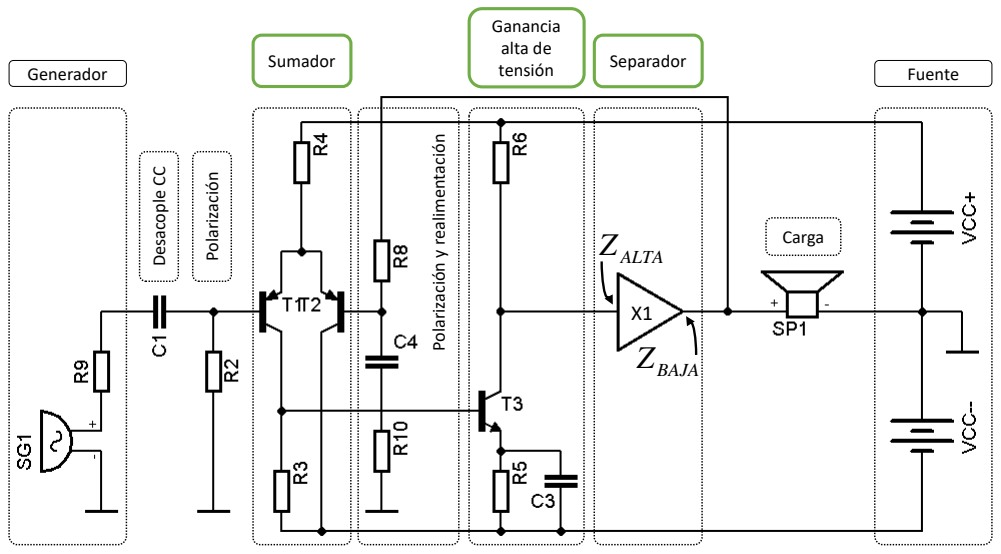
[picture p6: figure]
Ganancia alta de; tensión Sumador; Separador; ZBAJA; Z ALTA; Polarización; Carga; Generador; Desacople CC; Fuente

## Circuito con etapa de salida clase B (sin polarizar)

ETAPA DE
SALIDA

La topología de la etapa de salida clase B es mas eficiente pero agrega distorsión armónica

### Transferencia de la etapa de salida clase B

Sin corrección de cruce

- Los transistores T4 y T5 conducirán menos de 180° para una señal alterna VI
- La potencia que deberán disipar los colectores de T4 y T5 dependerá de VO

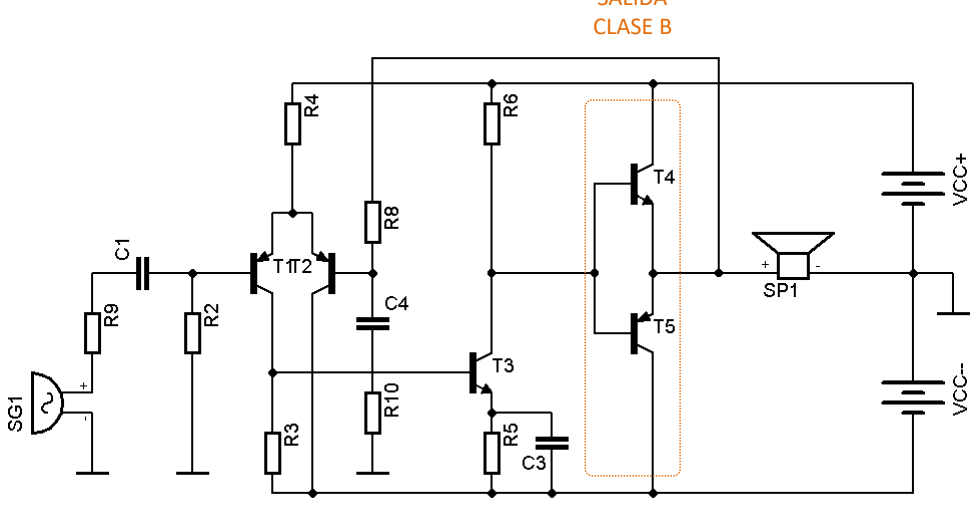
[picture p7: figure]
CLASE B

## Deformación de la señal de salida

## Distorsión armónica = 15% con Vi=3Vpico

VO

VI

VO

Notar la presencia de armónicas altas y la supremacía de las impares respecto de las pares, lo cual es típico de la distorsión por cruce.

## Análisis espectral de la señal de salida Corrección del cruce por polarización con diodos

VO

VI

VB4

VI

VI

VB5

VI

VCC+ VCC

−

T4

T5
VCEQ4 = -VCEQ5

VCE

ICQ4

Q

IC4
IC4MAX | --IC5MAX

--IC5

--ICQ5

VBEQ4 = -VBEQ5 ≅ 0,6V

### Polarización de los transistores con ICQ=1mA

t

VSP1=−VCE

t

IC4

IC IC5

Deformación de la señal de salida | Análisis espectral de la señal de salida
| Distorsión armónica = 2% con Vi=3Vpico

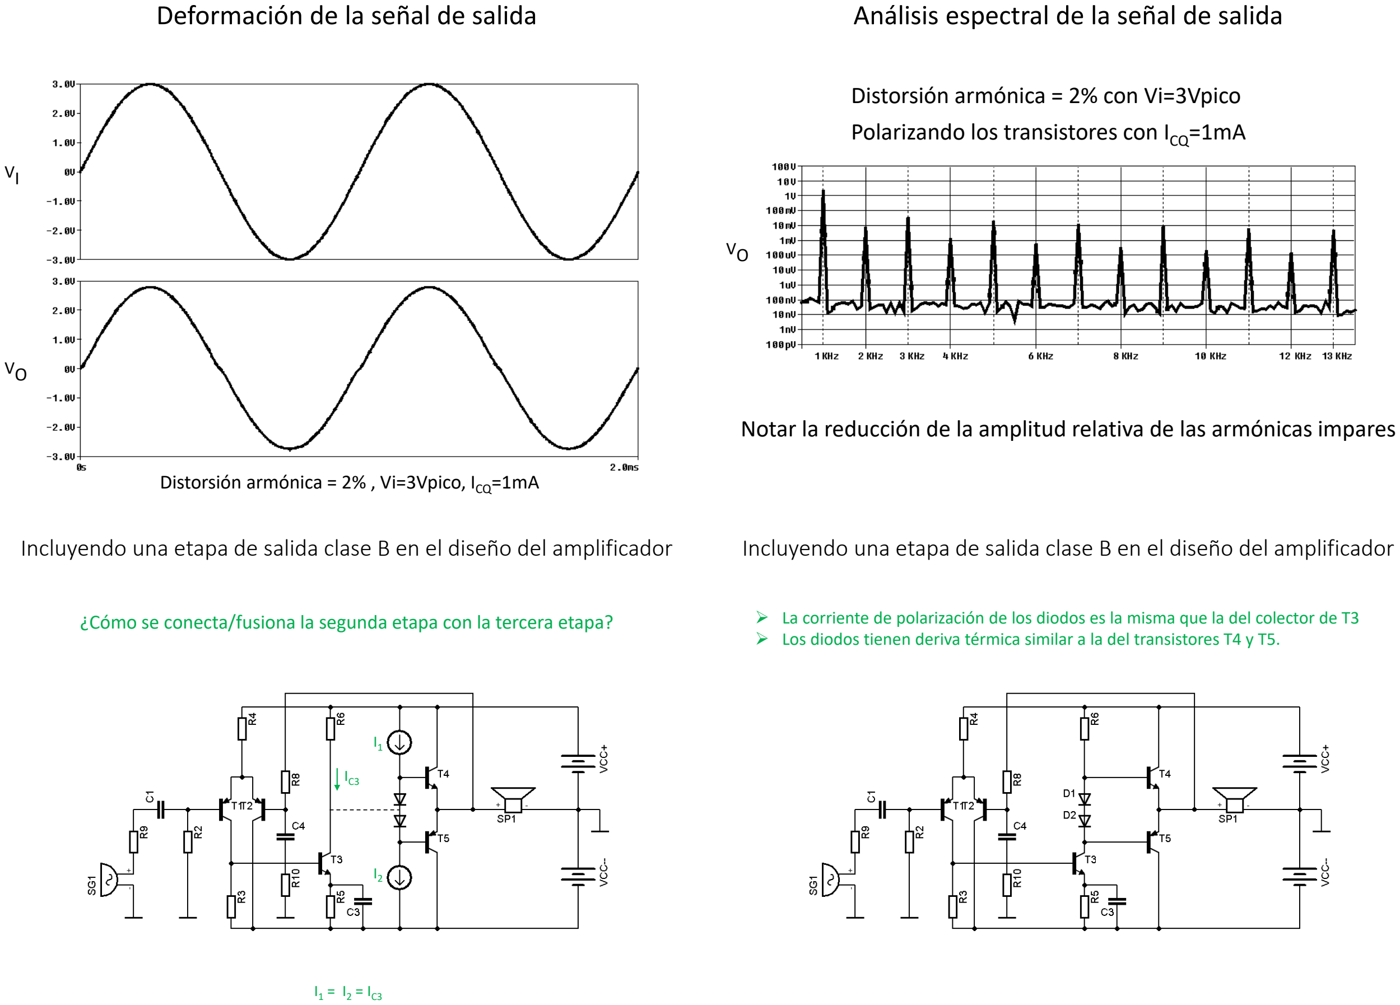
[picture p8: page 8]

VO

VI

Distorsión armónica = 2% , Vi=3Vpico, ICQ=1mA

VO

## Notar la reducción de la amplitud relativa de las armónicas impares

## Polarizando los transistores con ICQ=1mA

### Incluyendo una etapa de salida clase B en el diseño del amplificador

¿Cómo se conecta/fusiona la segunda etapa con la tercera etapa?

I1

I2

I1 = I2 = IC3

IC3

### Incluyendo una etapa de salida clase B en el diseño del amplificador

- La corriente de polarización de los diodos es la misma que la del colector de T3
- Los diodos tienen deriva térmica similar a la del transistores T4 y T5.

### Incluyendo una etapa de salida clase B en el diseño del amplificador

R permite un ajuste preciso de las corrientes de polarización ICQ4 e ICQ5

### Dinámica de la corriente por la carga y los transistores de salida

Para una excitación sinusoidal, T4 (T5) conduce solo en el hemiciclo positivo (negativo)

### Cálculo de la potencia generada en el transistor T4

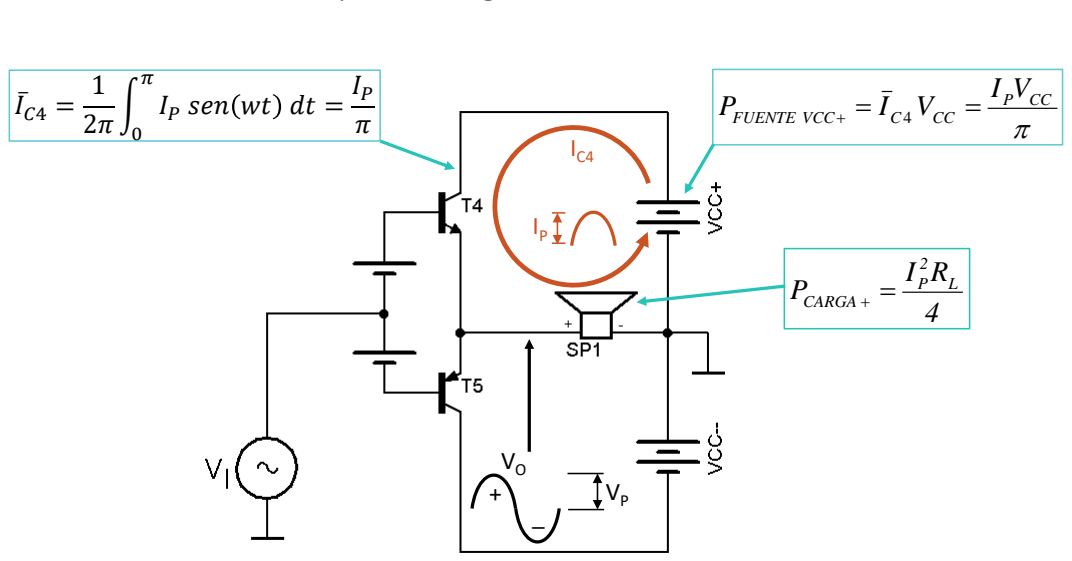
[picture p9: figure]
FUENTE VCC; CARGA + =; ̅IICCC =; IIPP ssssss wwww dd =; IIPP ππ

4

I R
π
I V P P | P | L

2
P CC | P
C = FUENTE VCC+ − CARGA+ = | −

Cálculo de la condición de mayor exigencia para disipación de calor en el transistor T4

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
I V d

dI

dP | CC | P L

P

L

2
P CC P

P

C | = | − | =

- −
=

¿A que amplitud de la tensión de salida corresponde la máxima disipación de potencia en cada transistor?

P | CC | CC | VCC V | 0,637V | 64% de
π

2 V

PCMAX

= | = | ≅

L

CC
P
π R

2V I

PCMAX

=

VP = RL IP

IP = Ip |PCMAX

La potencia disipada en cada transistor de salida (T4 o T5 en nuestro ejemplo) puede graficarse en función de la tensión pico de salida así:

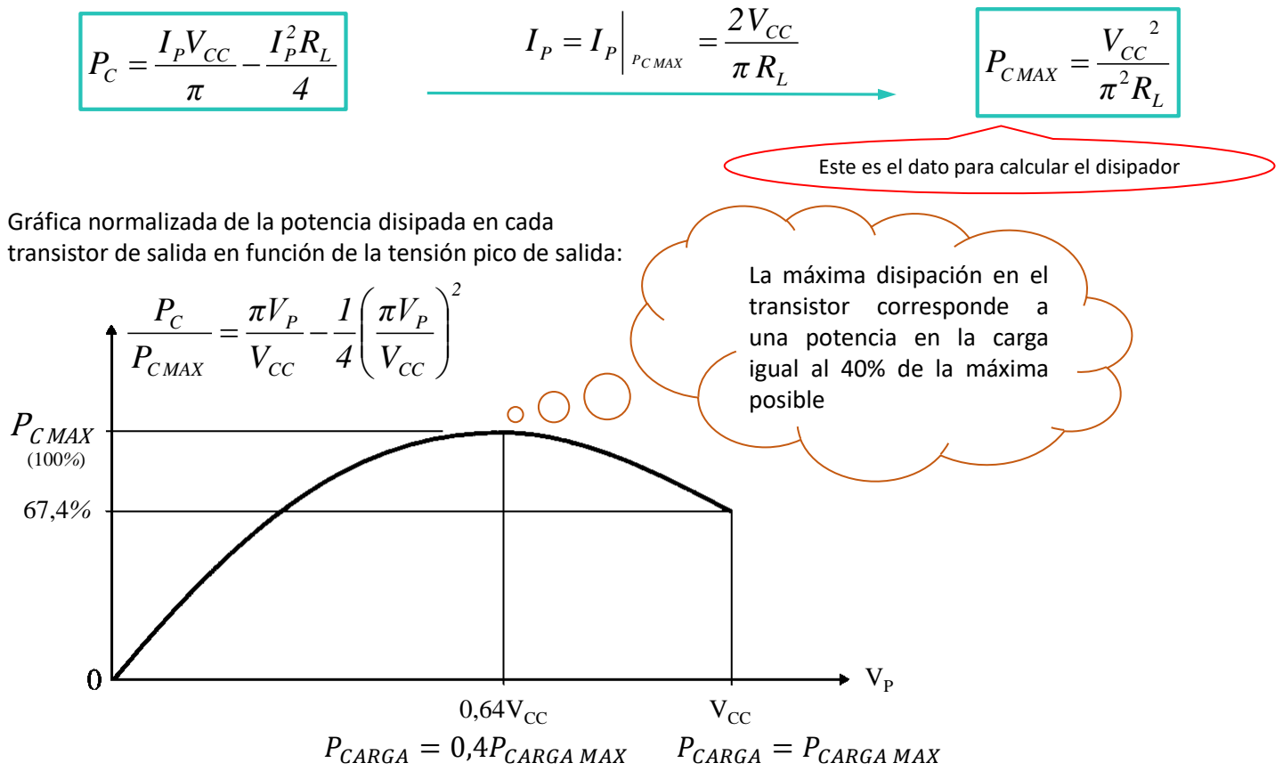
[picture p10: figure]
C MAX; PC MAX; 0,64VCC; VCC; PPCCCCCCCCCC = PPCCCCCCCCCC MM MM; La máxima disipación en el transistor corresponde a una potencia en la carga igual al 40% de la máxima posible; PPCCCCCCCCCC = 0,4PPCCCCCCCC MM MM

Gráfica normalizada de la potencia disipada en cada transistor de salida en función de la tensión pico de salida:

Este es el dato para calcular el disipador

¿Qué eficiencia puede lograrse con la etapa de salida clase B?

CC

P

P CC

P P

FUENTE

CARGA
V

V
4

π
2I V π

I V 2
P

P
η = | = | =

La máxima eficiencia es cuando Vp se acerca a VCC

| | 0,785 78%
V

V
4

π
η

CC

CC

max = | = | ≅

ηmax

VCC

VP

¿Cómo se relaciona la eficiencia con la potencia disipada en los transistores?

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
PCMAX | P | Pmax = | = | = | =

η

Los fabricantes suelen especificar PD en función de la temperatura de la cápsula

( ) | ( | ) c | co | c | co
j | co

D

D c | D | T T con T T
T | T
P P T P | − | ≥ − = | −

max

max
max

=150ºC
max

Tj

Tco

= 25ºC

max

max

D

j | co
P
T | T
jc | − θ =

# PPDDmax = 70WW

## Elección del transistor

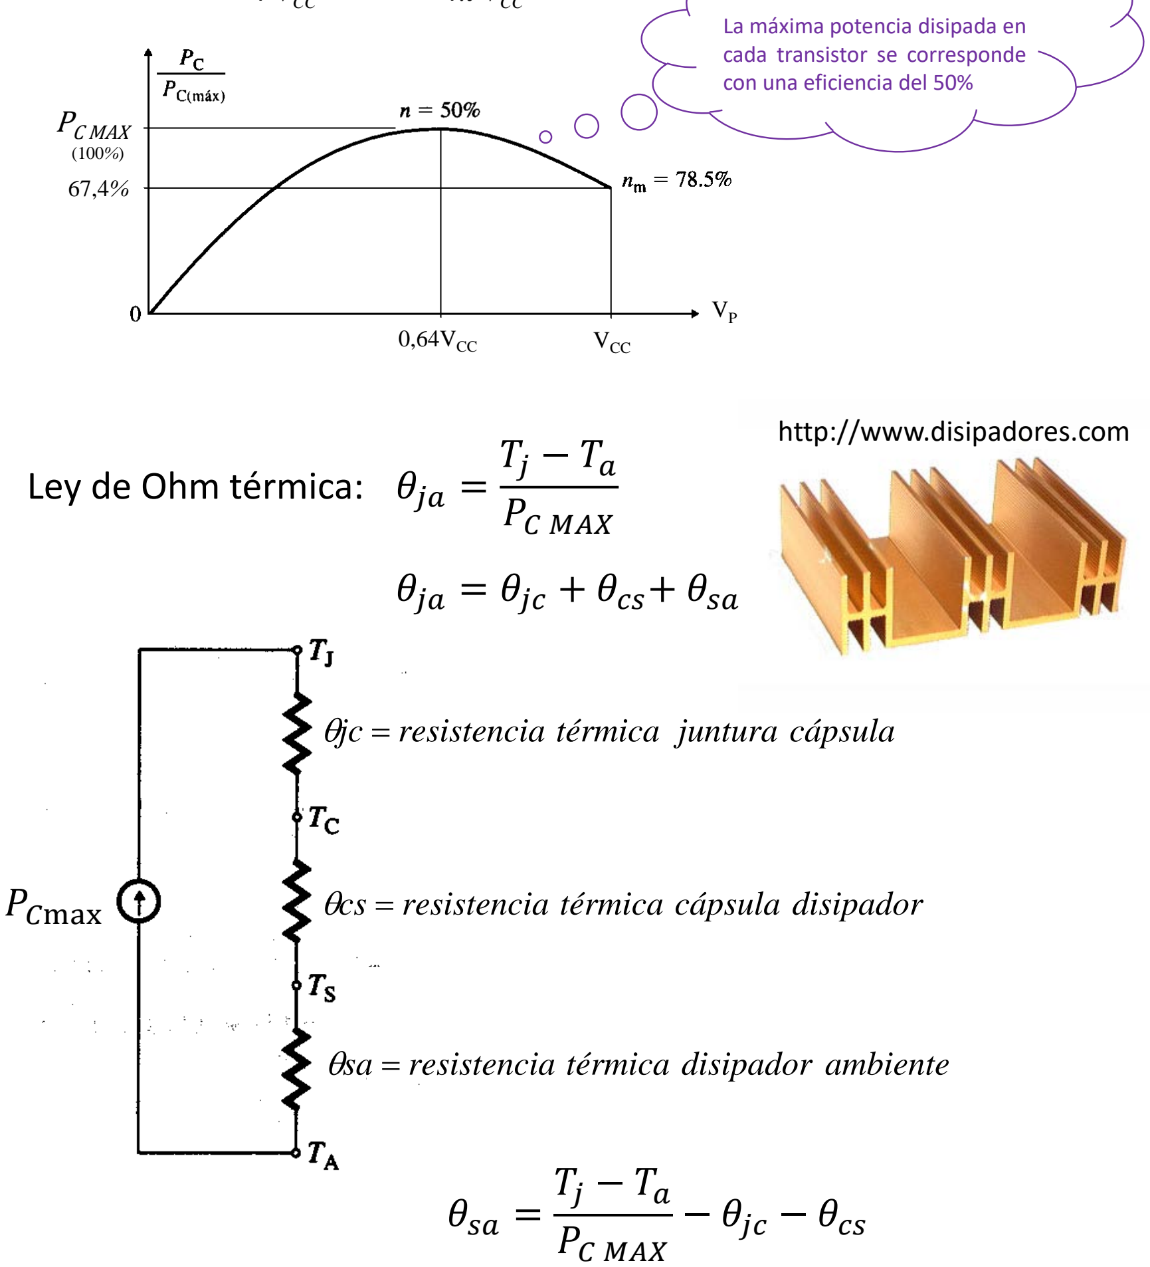
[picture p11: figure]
La máxima potencia disipada en cada transistor se corresponde con una eficiencia del 50%; PC MAX; VCC 0,64VCC; Ley de Ohm térmica:; http://www.disipadores.com; PPCCmax; TTjj − TT PPCC MM MM; − θθjj − θθcc; θθjj = θθjj + θθcc + θθssss; θθjj =

θjc = resistencia térmica juntura cápsula

θcs = resistencia térmica cápsula disipador

θsa = resistencia térmica disipador ambiente

# θθssss =

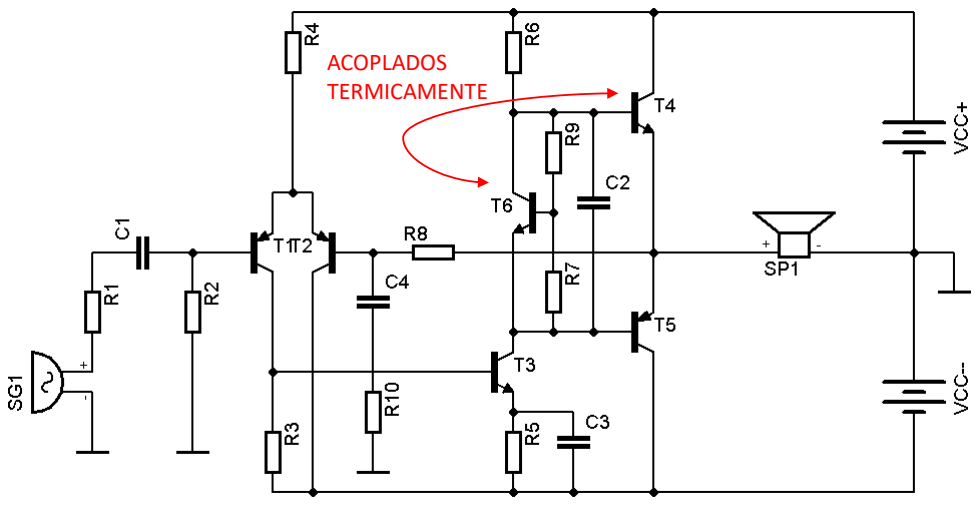
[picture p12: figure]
ACOPLADOS TERMICAMENTE

El transistor permite reemplazar a varios diodos y tiene las misma deriva térmica que la juntura base emisor de los transistores de salida

Incluyendo un multiplicador de Vbe en la polarización de la etapa de salida clase B

Mejorando la polarización de la etapa de salida | Mayor ganancia de tensión y menor impedancia de salida
| Se logra aumentando la ganancia de corriente de los transistores de salida (En este ejemplo, conectándolos en modo cuasi Darlington)

## Mayor estabilidad térmica de etapa de salida

Se logra agregando resistencias en serie con los emisores de los transistores de salida de manera de lograr estabilidad en su polarización por medio de realimentación local

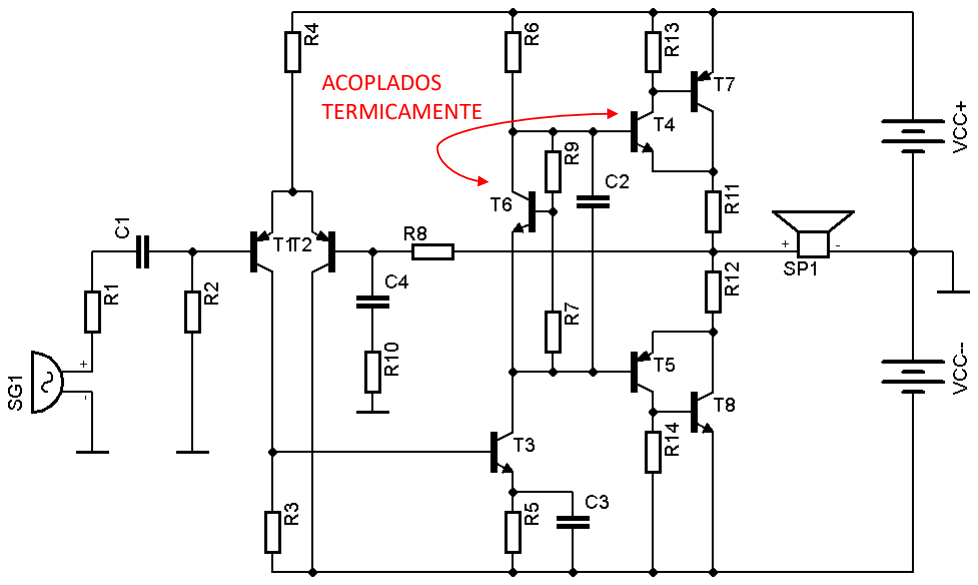
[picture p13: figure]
ACOPLADOS TERMICAMENTE

R11 y R12 se calculan considerando la disipación de calor de T4 | 43

# Cálculo del RE mínimo requerido para compensar el embalamiento térmico

E | C1 | B1 | C2 I = I + I + I
E | C1 | C2 I = I + I

## si β1 >> 1 ⇒ IB1 << IC1 ∴

Además es:

C2 2 C1 I = β I

Finalmente:

## I I (β 1) E

= C1 2 +

RE introduce realimentación local que permite compensar el embalamiento térmico de Q1

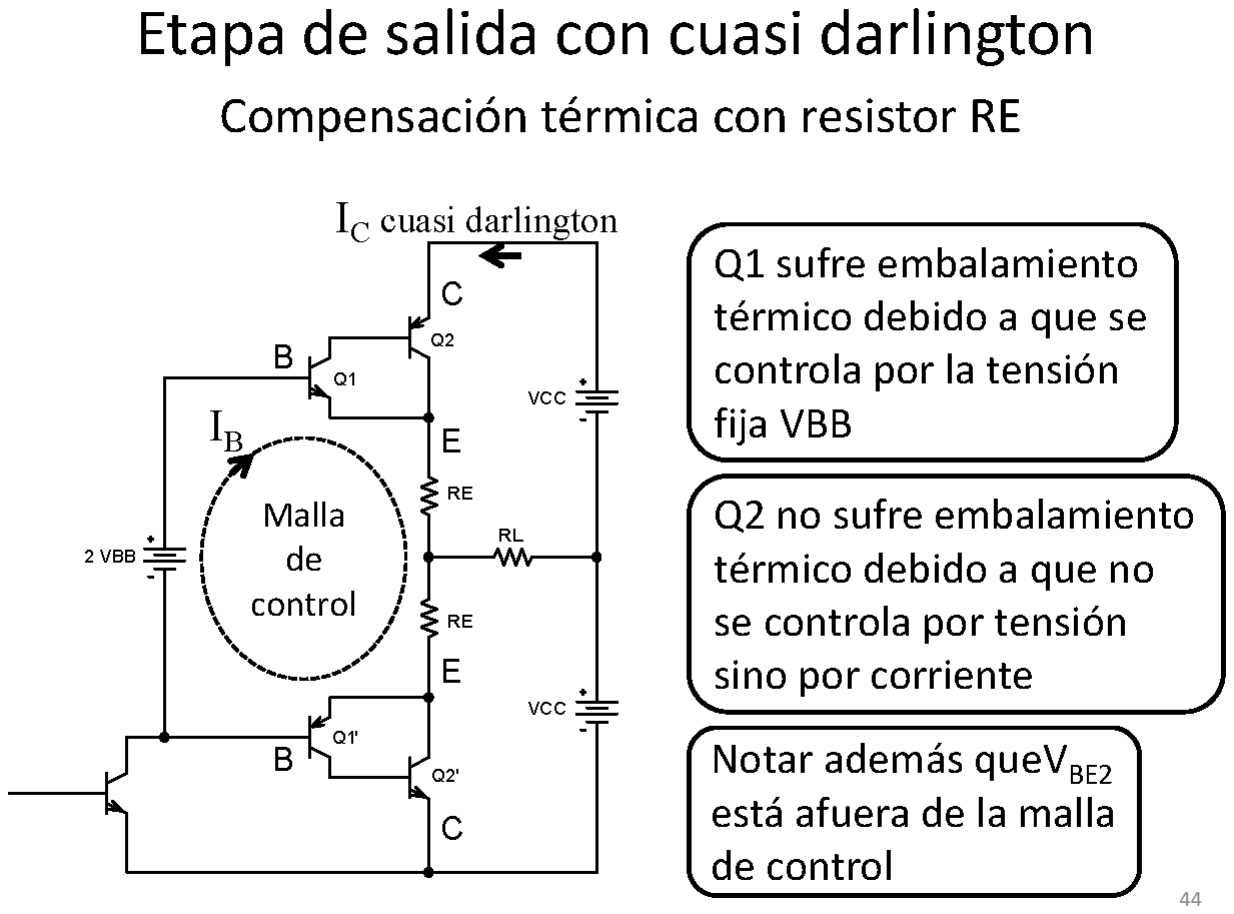
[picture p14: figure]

La corriente de emisor del transistor cuasi-darlington es:

E

BB | BE1
E | R
V V I | − =

Igualando con I I (β 1) E
= C1 2 + resulta:

R (β 1)

## V V I

E | 2
BB | BE1
C1
+

− =

La potencia generada en el transistor Q1 es:

G CE C1 P =V I

Con lo que resulta:

R (β 1)

## V V P V

E | 2
BB | BE1
G | CE
+

− =

Para evitar el embalamiento térmico, la generación de calor debe ser menor a la capacidad de disiparlo, por lo que debe cumplirse que:

La variación de potencia disipada es:

R (β 1)

V K
Tj

P

E | 2
G | CE
+

=
∂

∂

La potencia disipable en el transistor Q1 , por ley de Ohm térmica es:

ja

## Tj Ta PD θ

− =

Tj

P
Tj

PD G
∂

∂ ≥
∂

∂

## Tj ja

PD
θ

1
=
∂

∂

Y la variación de potencia generada es:
VBE1 con K | 2 mV/º C
Tj

∂ =− = ∂

En su forma más conocida:

Notar que para el cuasi-darlington estudiado (NPN-PNP), el transistor que puede embalarse térmicamente es Q1, que además es el que cierra la malla de polarización estabilizada, por lo que debe considerarse para el cálculo de RE la manera en que éste transistor disipará su potencia, o sea el valor resultante de θja según se utilice o no disipador térmico, luego puede calcularse RE . Además será:

R (β 1)

V K
ja | E | 2 CE
+

≥
θ
Combinando resulta en: | 1
( | )
V K

## R β 1 ja

CE

E 2 + θ ≤

VCE

=VCE MAX

=VCC | y | 2 | 2MIN β = β

Finalmente:
(β 1)

## ja V K

R

2MIN

1 CC
E
+

≥

θ Q

## Mayor ganancia de tensión y menor impedancia de salida

Se logra aumentando la ganancia de corriente de los transistores de salida (En este ejemplo, conectándolos en modo Darlington)

R11 y R12 no se calculan igual que para el caso cuasi Darlington

Se incrementa la ganancia de tensión de la segunda etapa mediante el aumento de la impedancia vista por el colector del transistor T3

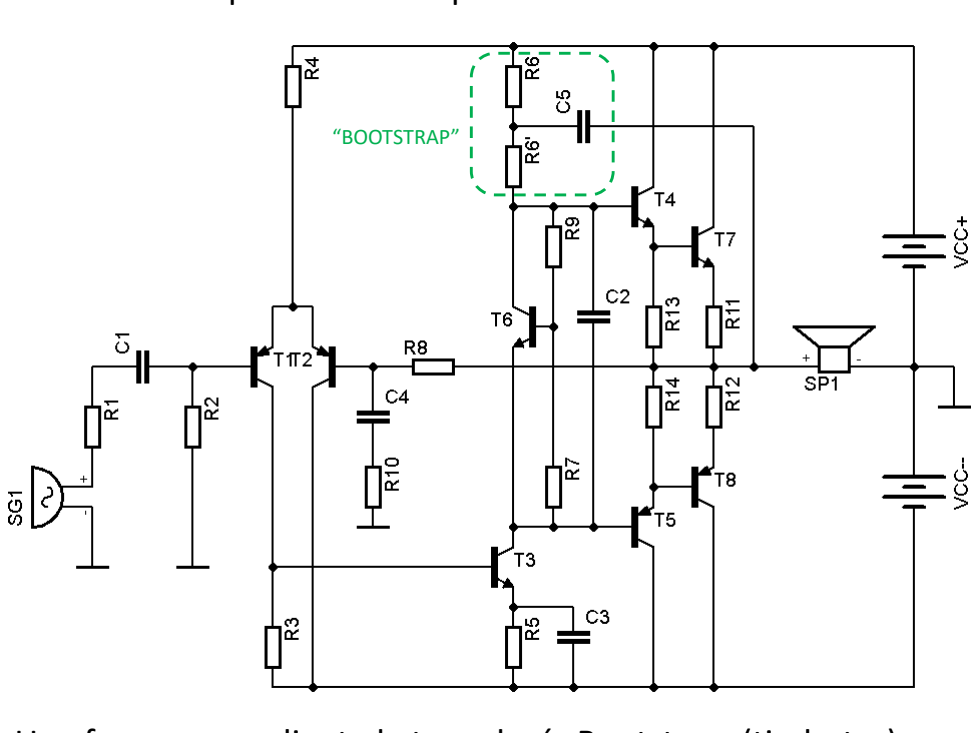
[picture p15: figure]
“BOOTSTRAP”

- Una forma es mediante la tecnología Bootstrap (tirabotas).

## Mejoramiento del comportamiento de la segunda etapa Funcionamiento del circuito bootstrap (tira botas)

La ganancia de tensión de la segunda etapa será gmT3 . RO T3 // Z // Zi etapa3

Mediante la implementación de una carga activa

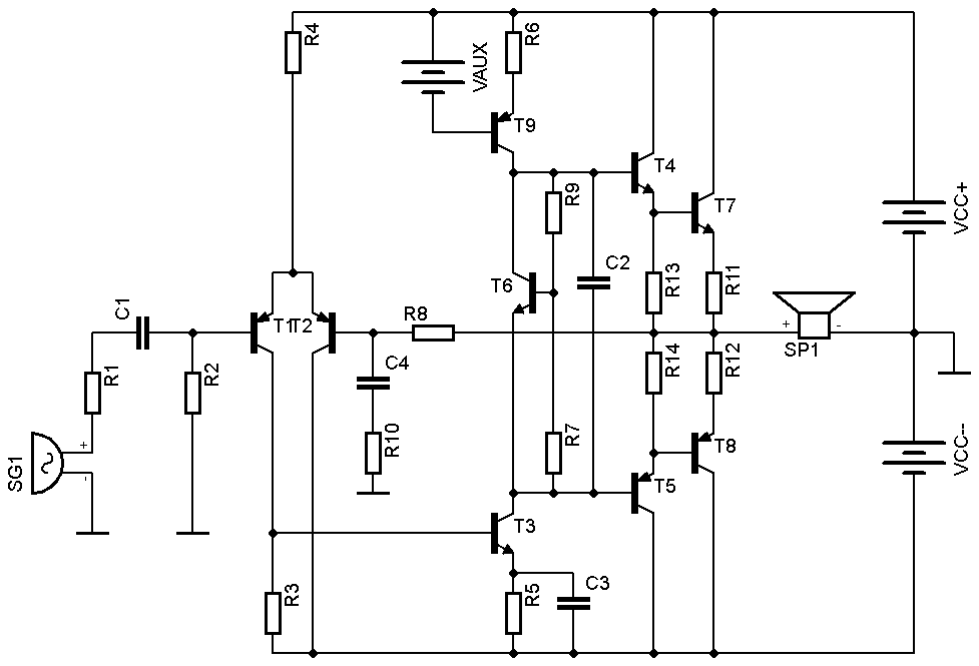
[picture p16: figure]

La ganancia de tensión de la segunda etapa será gmT3 . RO T3 // RO T9 // Zi etapa3

## Mejoramiento del comportamiento de la segunda etapa

- La batería auxiliar se reemplaza por una tensión de referencia lograda con dos diodos

Mejoramiento del comportamiento de la segunda etapa Mejoramiento del comportamiento de la primera etapa

- Se reemplaza la resistencia de polarización del par diferencial por una fuente de corriente
- Se logra mejorar el manejo de tensiones de modo común y el CMRR

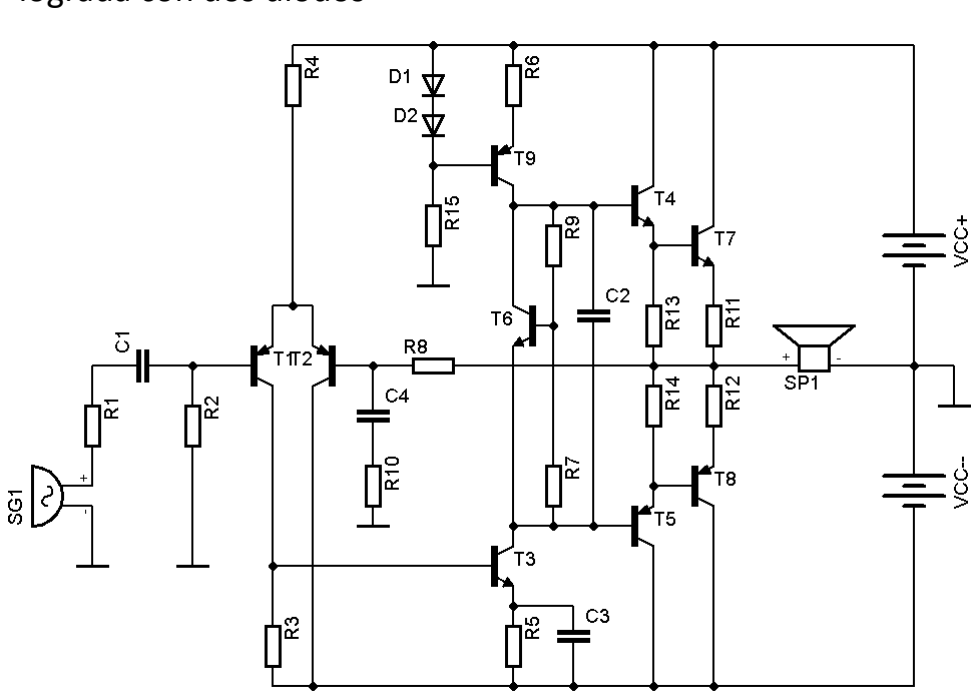
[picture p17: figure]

### Mejoramiento del comportamiento de la primera etapa

- Otra mejora importante es reemplazar la carga resistiva de T1 por una activa lograda con un espejo de corriente
- Se logra duplicar la ganancia de la primera etapa

- Para mejorar la linealidad de la etapa de entrada se agrega
realimentación local por medio de resistencias en los emisores

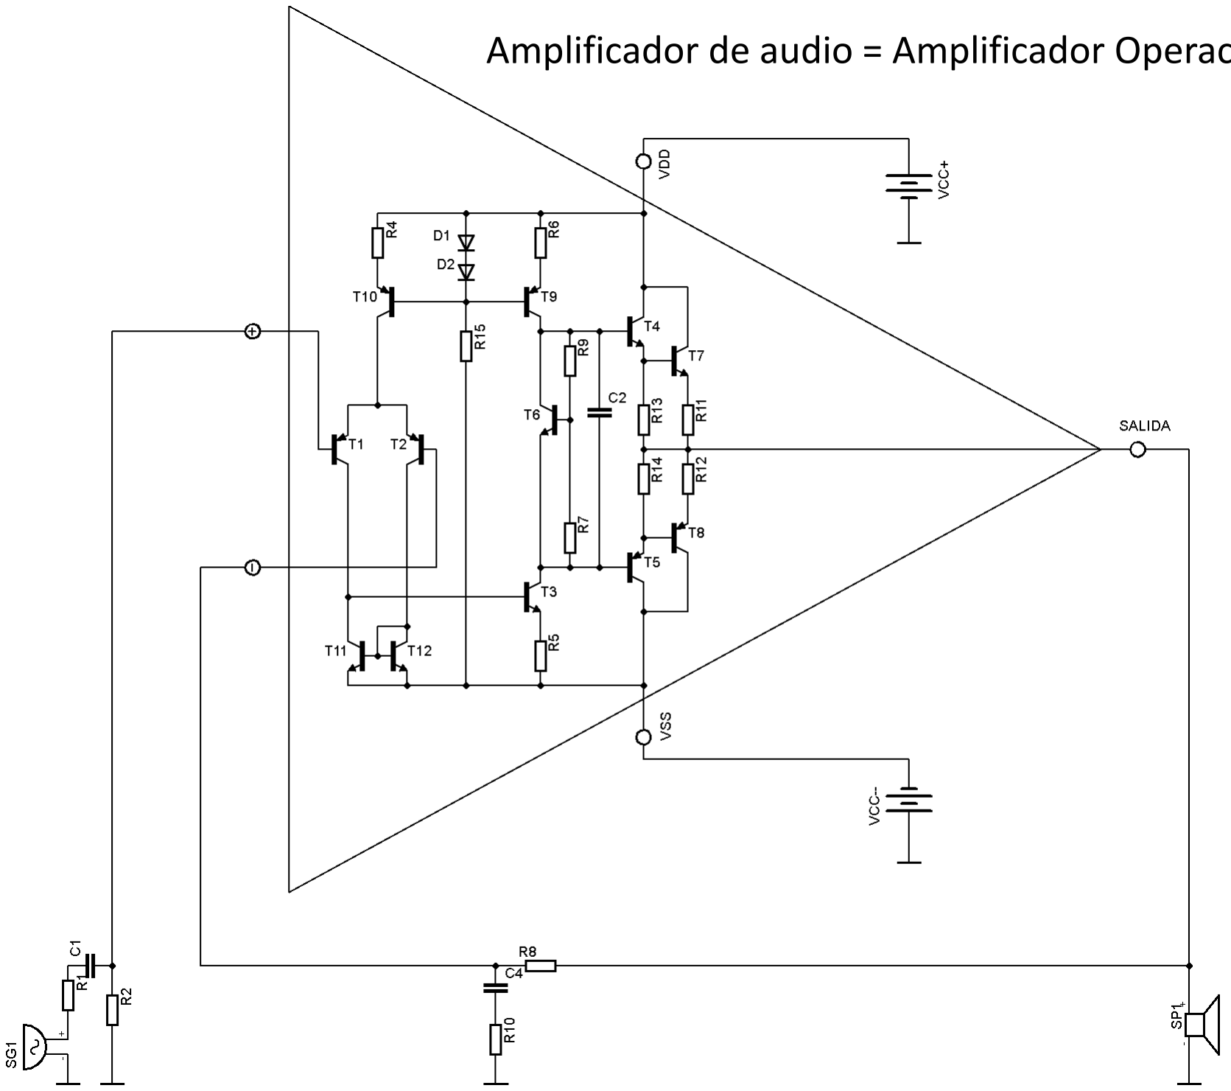
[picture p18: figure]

Mejoramiento del comportamiento de la primera etapa | Amplificador de audio = Amplificador Operacional

# Especificaciones típicas

Potencia de salida = 50W sobre 8 ohm a 1KHz con THD 0,01% Potencia de salida = 80W sobre 4 ohm a 1KHz con THD 0,02% Distorsión armónica total = 0,05% de 20 Hz a 20KHz a 1W/8ohm Distorsión por intermodulación = 0,05 % a 1W/8ohm
Distorsión por intermodulación transitoria (TIM)= rara vez especificado Ancho de banda = 10 Hz a 100 KHz a 1W/8ohm
Ancho de banda de potencia (limitado por “slew rate”) = 50 KHz a 50W/8ohm Sobreimpulso de la tensión de salida = rara vez especificado
Factor de amortiguamiento = 200
Impedancia de entrada = 50 Kohm de 20 Hz a 20KHz
Corrimiento de la tensión de salida = ±20mV entre 20 y 50 ºC de temp. amb. Ruido = mejor que 90dB de relación señal ruido o 10uV RMS máx. a la salida Consumo sin señal = 5W
Protección contra cortocircuito a la salida
Protección contra tensión continua a la salida

Amplificador de audio de potencia

# Distorsión armónica

# Esquema de un amplificador de audio de potencia

# Medición o simulación a lazo abierto

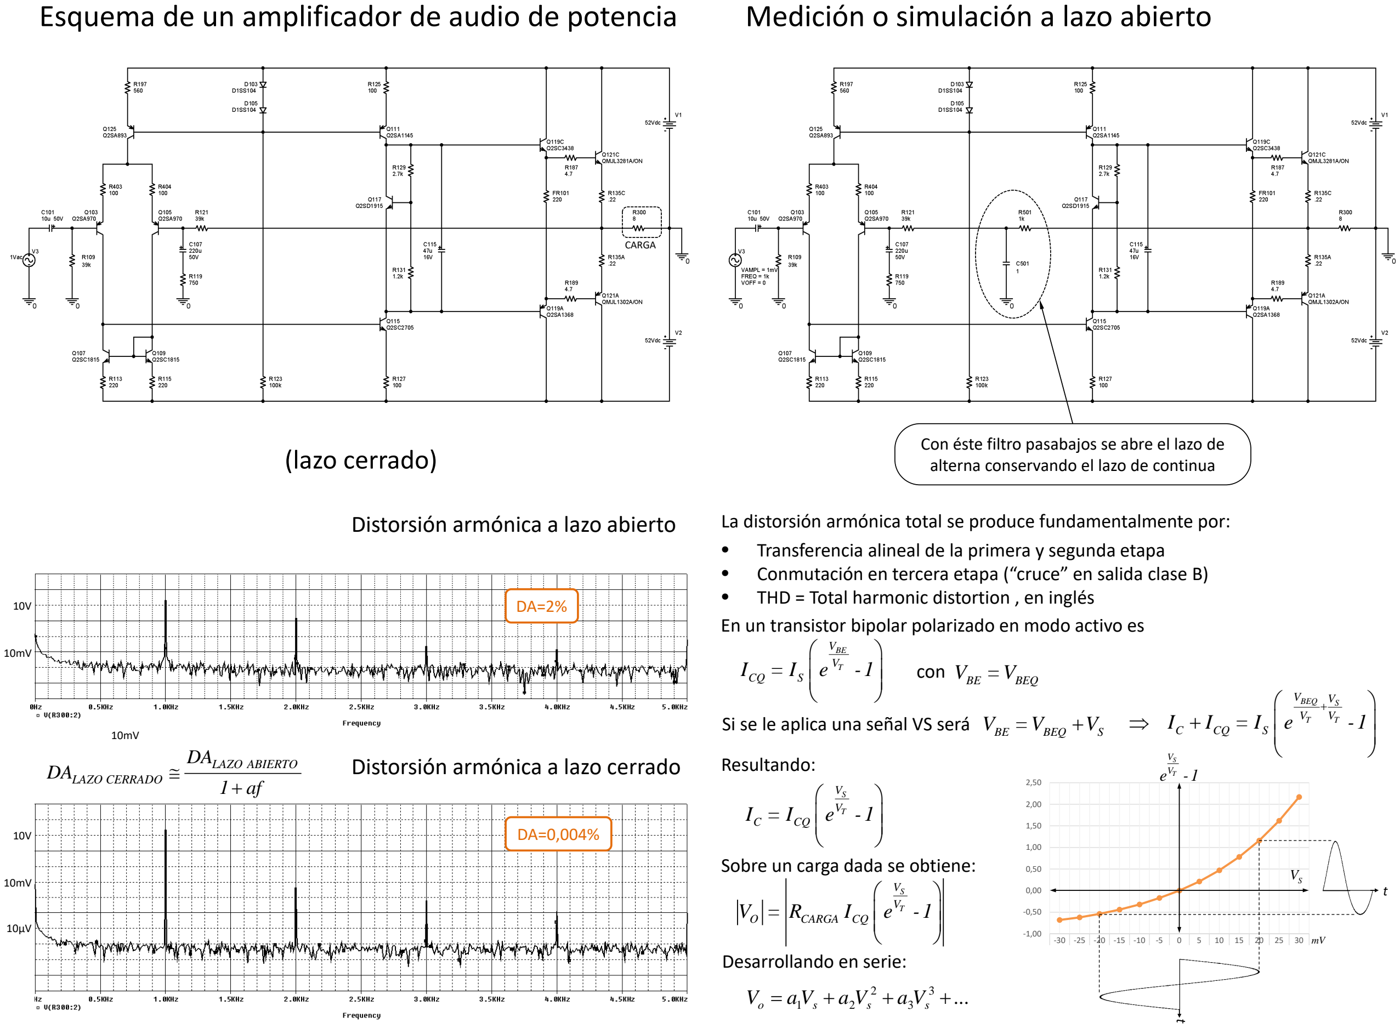
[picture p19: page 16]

## (lazo cerrado)

CARGA

Con éste filtro pasabajos se abre el lazo de alterna conservando el lazo de continua

## Distorsión armónica a lazo abierto

## Distorsión armónica a lazo cerrado

DA=2%

DA=0,004%

1 af

DA
DA | LAZO ABIERTO
LAZO CERRADO
+

≅

10mV

10V

10µV

10mV

10V

10mV

-30 | -25 | -20 | | -15 | -10 | -5 | 0 | 5 | 10 | 15 | | 20 | 25 | 30
Series1 | -0,6 | -0,6 | -0,5 | | -0,4 | -0,3 | -0,1 | 0,00 | 0,21 | 0,47 | 0,78 | 1,16 | | 1,62 | 2,17

-1,00

-0,50

0,00

0,50

1,00

1,50

2,00

2,50

La distorsión armónica total se produce fundamentalmente por:
- Transferencia alineal de la primera y segunda etapa
- Conmutación en tercera etapa (“cruce” en salida clase B)
- THD = Total harmonic distortion , en inglés
En un transistor bipolar polarizado en modo activo es

... ³
3

2 Vo
= a1

Vs + a2

Vs + a Vs +

Sobre un carga dada se obtiene:

Si se le aplica una señal VS será V =V | V BE | BEQ | S +
Resultando:
BEQ | S
T | T
V | V
V | V
C | CQ | S I I = I e | -1
- +
+ | | | |

BE
T

V
V
CQ | S I = I e -1

⇒

S
T

V
V
C | CQ I = I e -1

S
T

V
V V | = R | I e -1 O | CARGA CQ

S
T

V
V e -1

Desarrollando en serie:

VS
t

t

mV

con V =V BE BEQ

Con señal sinusoidal | se puede expresar:
V a V senowt a V seno wt a V seno wt ... ³ | 3
3 s

2 2
o
= 1 s | + 2 s | + | +
∧ | ∧ | ∧

## Definiendo distorsión armónica como la relación entre la suma de las componentes armónicas a la fundamental, se tiene para las componentes segunda y tercera armónica:

## V V seno(wt) S S ∧

=

2

1

3
3
3 | 24

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
### Resulta evidente la necesidad de exitar la segunda etapa con bajos niveles de señal y que a su vez la misma provea una alta ganancia de tensión

## Siendo:

T

CARGA Q
V
R | I
a1 = | 2 | 2 2 T CARGA Q
V
R | I
a = | 3 | 3 6 T CARGA Q
V

R I
a =
( | ) | (3senowt seno3wt) ... 4

a V 1 cos 2wt
2

a V V a V senowt

3
3 s

2
2 s
o = 1 s | + | − | + | − | +
∧ | ∧
∧

seno3wt ... 4

a V
cos 2wt
2

a V
senowt
4

3a V
a V
2

a V V

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
o | − | − | +

= | + | +
∧ | ∧ | ∧
∧

∧

# Distorsión de cada etapa

## - Se mantiene el circuito realimentado para

sostener la correcta polarización.
- Se neutraliza la realimentación de alterna.
- Se busca medir cada etapa por separado,

## independizándola del efecto de carga de las

otras.

# PRIMERA ETAPA

VENT

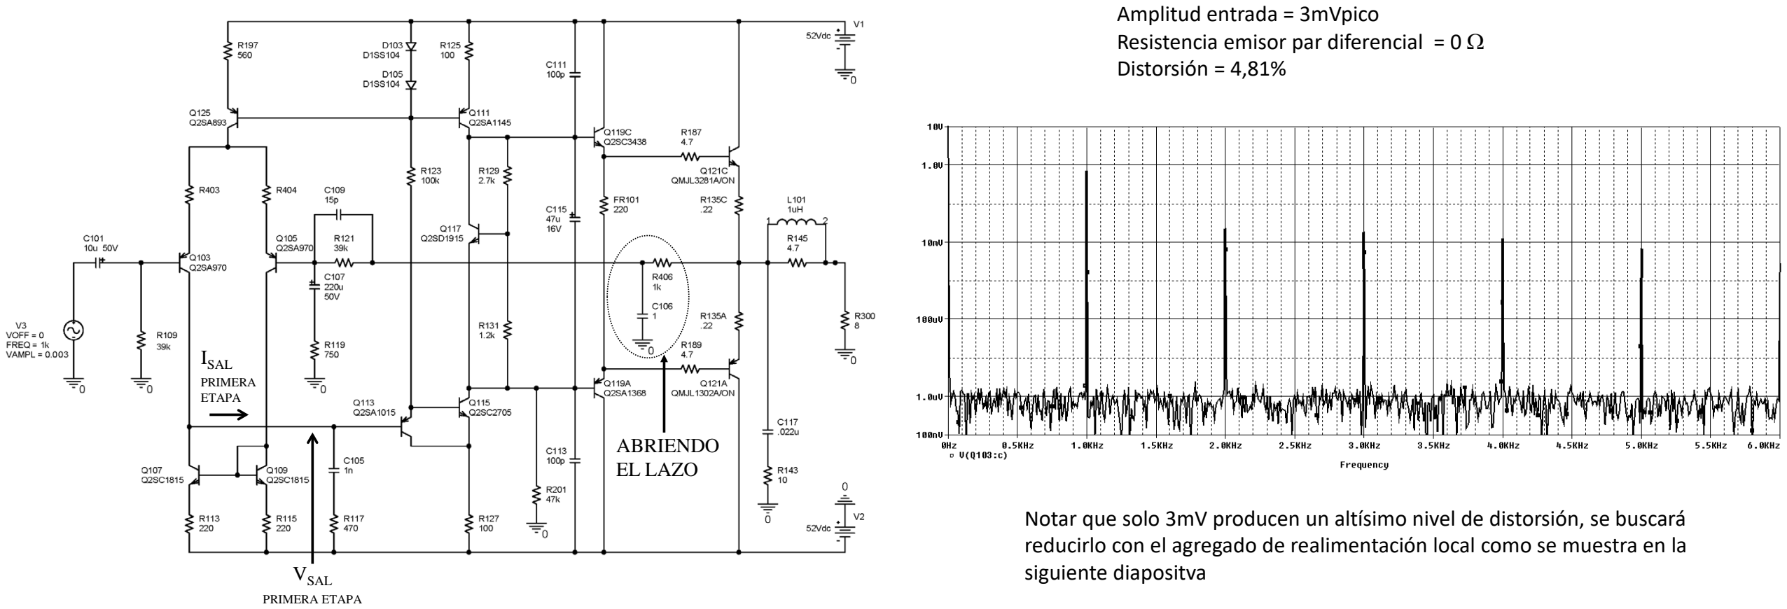
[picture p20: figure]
VSAL; PRIMERA ETAPA; ABRIENDO EL LAZO; ISAL; Amplitud entrada = 3mVpico; Distorsión = 4,81%; siguiente diapositva

Resistencia emisor par diferencial = 0 Ω

Notar que solo 3mV producen un altísimo nivel de distorsión, se buscará reducirlo con el agregado de realimentación local como se muestra en la

Amplitud entrada = 3,5mVpico Resistencia emisor par diferencial = 100 Ω Distorsión = 0,02%

El costo es una reducción de ganancia de 10dB.
El beneficio es una reducción de la distorsión de mas de 40 dB.
Notar que la componente segunda armónica es muy alta en relación a la tercera, cuando se esperaba que hubiera ocurrido cancelación debido al uso
del espejo de corriente como carga activa | 688uA | 703uA

Notar que las corrientes de colector del par diferencial son levemente diferentes

688uA

703uA

Se propone medir la corriente de salida del par diferencial mediante una resistencia de 1 ohm

ABRIENDO
EL LAZO ISAL
PRIMERA
ETAPA

I = 0

VENT
DIFERENCIAL

Carga casi ideal para una fuente de corriente

La segunda y tercera armónica tienen un peso importante en la distorsión 695,5uA 695,5uA

Se agrega una resistencia y se ajusta su valor para equilibrar las dos corrientes de colector como se muestra en el siguiente esquema

ABRIENDO
EL LAZO ISAL
PRIMERA
ETAPA

VENT
DIFERENCIAL

I = 0

La segunda resulta muy reducida respecto de la tercera

# SEGUNDA ETAPA

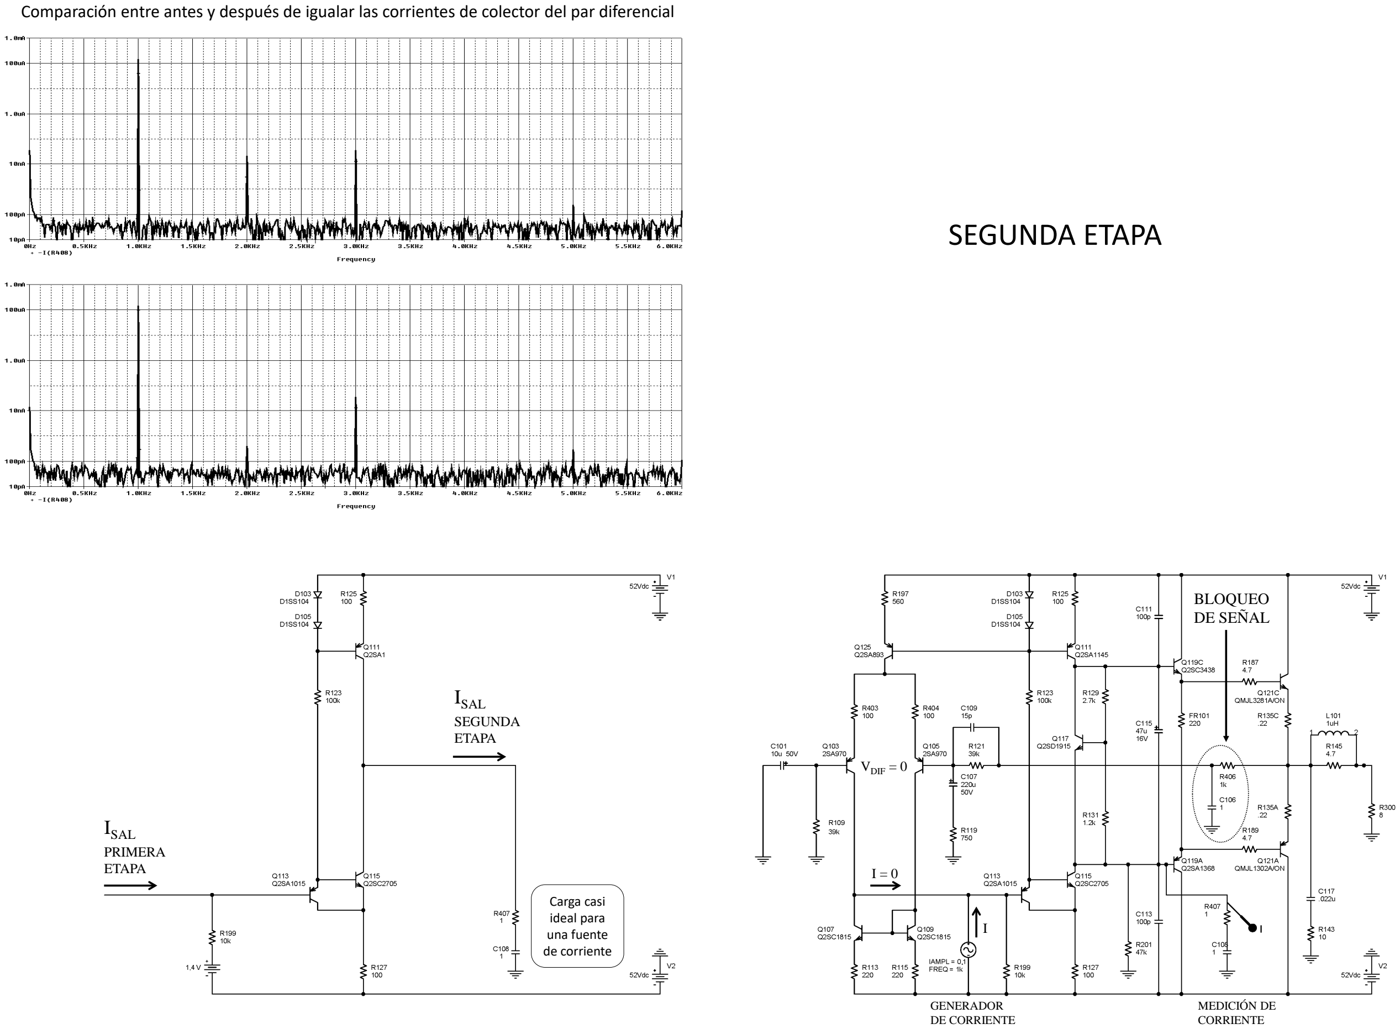
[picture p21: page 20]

Comparación entre antes y después de igualar las corrientes de colector del par diferencial

ISAL
SEGUNDA
ETAPA

ISAL
PRIMERA
ETAPA
Carga casi
ideal para
una fuente
de corriente

BLOQUEO
DE SEÑAL

GENERADOR
DE CORRIENTE

I = 0

I

VDIF = 0

MEDICIÓN DE
CORRIENTE

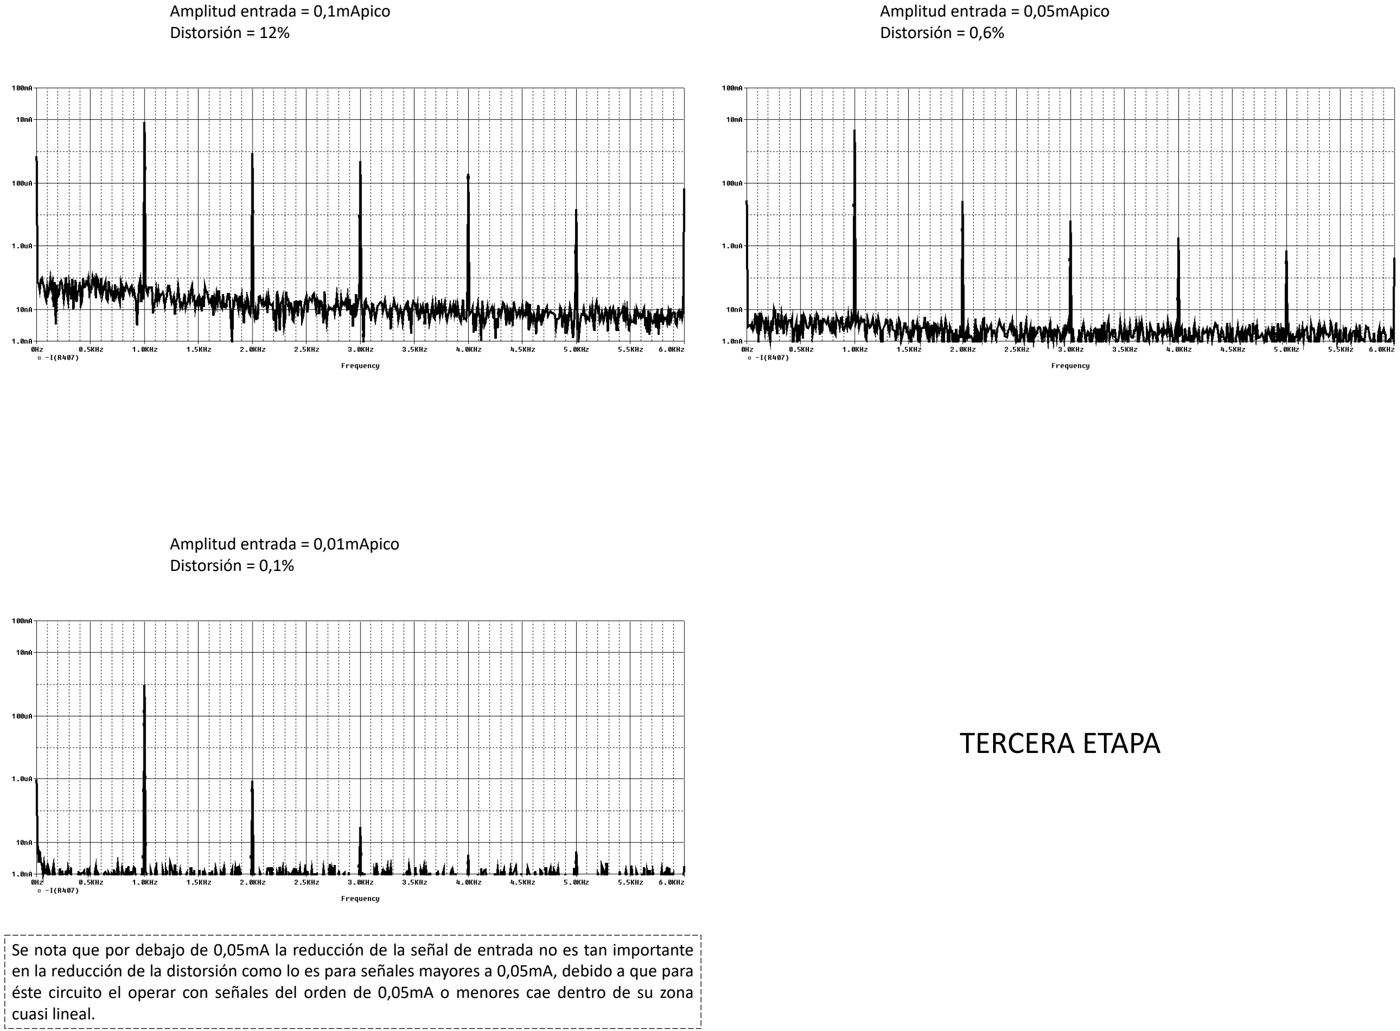
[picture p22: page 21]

Amplitud entrada = 0,1mApico Distorsión = 12%

Amplitud entrada = 0,05mApico Distorsión = 0,6%

Amplitud entrada = 0,01mApico Distorsión = 0,1%

Se nota que por debajo de 0,05mA la reducción de la señal de entrada no es tan importante en la reducción de la distorsión como lo es para señales mayores a 0,05mA, debido a que para éste circuito el operar con señales del orden de 0,05mA o menores cae dentro de su zona cuasi lineal.

# TERCERA ETAPA

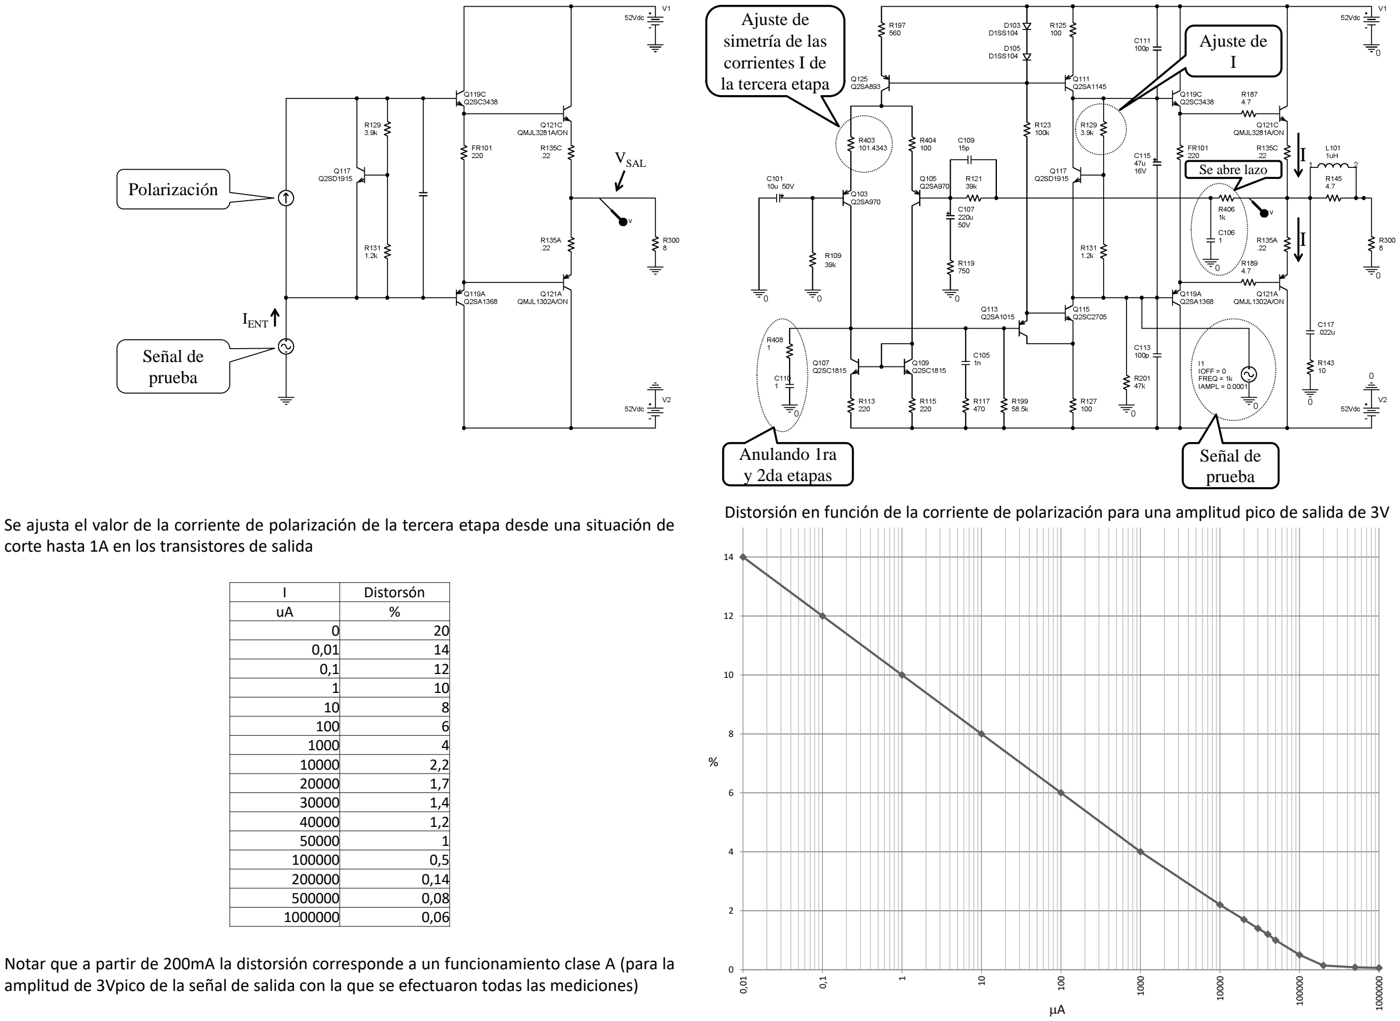
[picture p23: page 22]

Polarización

IENT
Señal de
prueba

VSAL

I

I

Ajuste de
simetría de las
corrientes I de
la tercera etapa

Ajuste de
I

Señal de
prueba

Se abre lazo

Anulando 1ra
y 2da etapas

Notar que a partir de 200mA la distorsión corresponde a un funcionamiento clase A (para la amplitud de 3Vpico de la señal de salida con la que se efectuaron todas las mediciones)

Se ajusta el valor de la corriente de polarización de la tercera etapa desde una situación de corte hasta 1A en los transistores de salida

I | Distorsón
uA | %
0 | 20
0,01 | 14
0,1 | 12
1 | 10
10 | 8
100 | 6
1000 | 4
10000 | 2,2
20000 | 1,7
30000 | 1,4
40000 | 1,2
50000 | 1
100000 | 0,5
200000 | 0,14
500000 | 0,08
1000000 | 0,06

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
0,01

0,1

1
10

100
1000
10000
100000

1000000

Distorsión en función de la corriente de polarización para una amplitud pico de salida de 3V

µA

%

Notar que la distorsión disminuye a medida que aumenta la amplitud. Sin embargo al acercarse al recorte de la etapa de salida vuelve a crecer. Ver el gráfico siguiente

¿Cómo varía la distorsión de la señal de salida del amplificador en función de su amplitud?
(Solo la tercera etapa más el efecto de carga de la segunda)

Se midió para una corriente I=10mA obteniéndose los siguientes valores.

Vo | Distorsón
V | %
1 | 3,1
3 | 2,2
6 | 1,7
13,1 | 1,15
16 | 1,05
20 | 1,1
22,5 | 1,3
25,4 | 1,6
28,2 | 2,1
30 | 2,6
35 | 4
40 | 5,3

Distorsión en función de la amplitud pico de salida para I=10mA

## Analizar el amplificador de potencia del Turner 730

Se ajustará PS401 para conseguir 0V sobre RL con VG=0V y se ajustará PS402 para conseguir una corriente de colector de Q407 y Q408 de 10mA con VG=0V

1) Calcular las tensiones de todos los nodos y las corrientes de todas la ramas para VG=0V
2) Calcular la ganancia de lazo para frecuencias medias (1KHz)
3) Calcular la ganancia global para frecuencias medias (1KHz)
4) Calcular la máxima potencia obtenible sobre la carga para frecuencias medias (1KHz)
5) Calcular la impedancia de entrada para frecuencias medias (1KHz)
6) Calcular la impedancia de salida para frecuencias medias (1KHz)
7) Calcular el factor de amortiguamiento para frecuencias medias (1KHz)
8) Calcular la máxima tensión pico sobre la carga para frecuencias medias (1KHz)
9) Calcular la máxima eficiencia obtenible con éste amplificador para frecuencias medias (1KHz)
10) Determinar:
a) El tamaño de los disipadores para cada transistor (resistencia térmica disipador-ambiente)
b) Encontrar el disipador comercial que podría utilizarse para construir un prototipo funcional
c) Comparar con los disipadores utilizados originalmente por Turner y obtener conclusiones
11) Simular el comportamiento estático y dinámico del amplificador determinando:
a) Medir las tensiones de todos los nodos y las corrientes de todas la ramas para VG=0V
b) Medir la impedancia de entrada en función de la frecuencia (desde 0,1Hz hasta 1GHz)
c) Medir la impedancia de salida en función de la frecuencia (desde 0,1Hz hasta 1GHz)
d) Respuesta en frecuencia para 1W sobre la carga
e) Ancho de banda de potencia
Es la máxima frecuencia para la que el amplificador logra reproducir una señal sinusoidal a máxima potencia (hallada en el punto 4 sin deformación
f) Respuesta al escalón
i. Pequeña señal (la tensión pico de salida estará entre 0,1V y 1V)
ii. Gran señal (amplitud de salida apenas menor que la máxima tensión pico de salida hallada en el punto 8
iii. En base a lo medido en i. determinar el ancho de banda para pequeña señal asumiendo que el amplificador está compensado por polo dominante
iv. En base a lo medido en ii. determinar la velocidad de crecimiento de la tensión de salida (“slew rate”)
g) Determinar el margen de fase
h) Determinar la distorsión armónica a 1KHz y a 10KHz para potencias de 0,1W; 1W; 10W y 90% de la máxima calculada en el punto 4
i) Determinar la distorsión por intermodulación para potencias de 0,1W; 1W; 10W y 90% de la máxima calculada en el punto 4
j) Determinar el Rechazo de Ruido de la Fuente de Alimentación (“PSNR”)

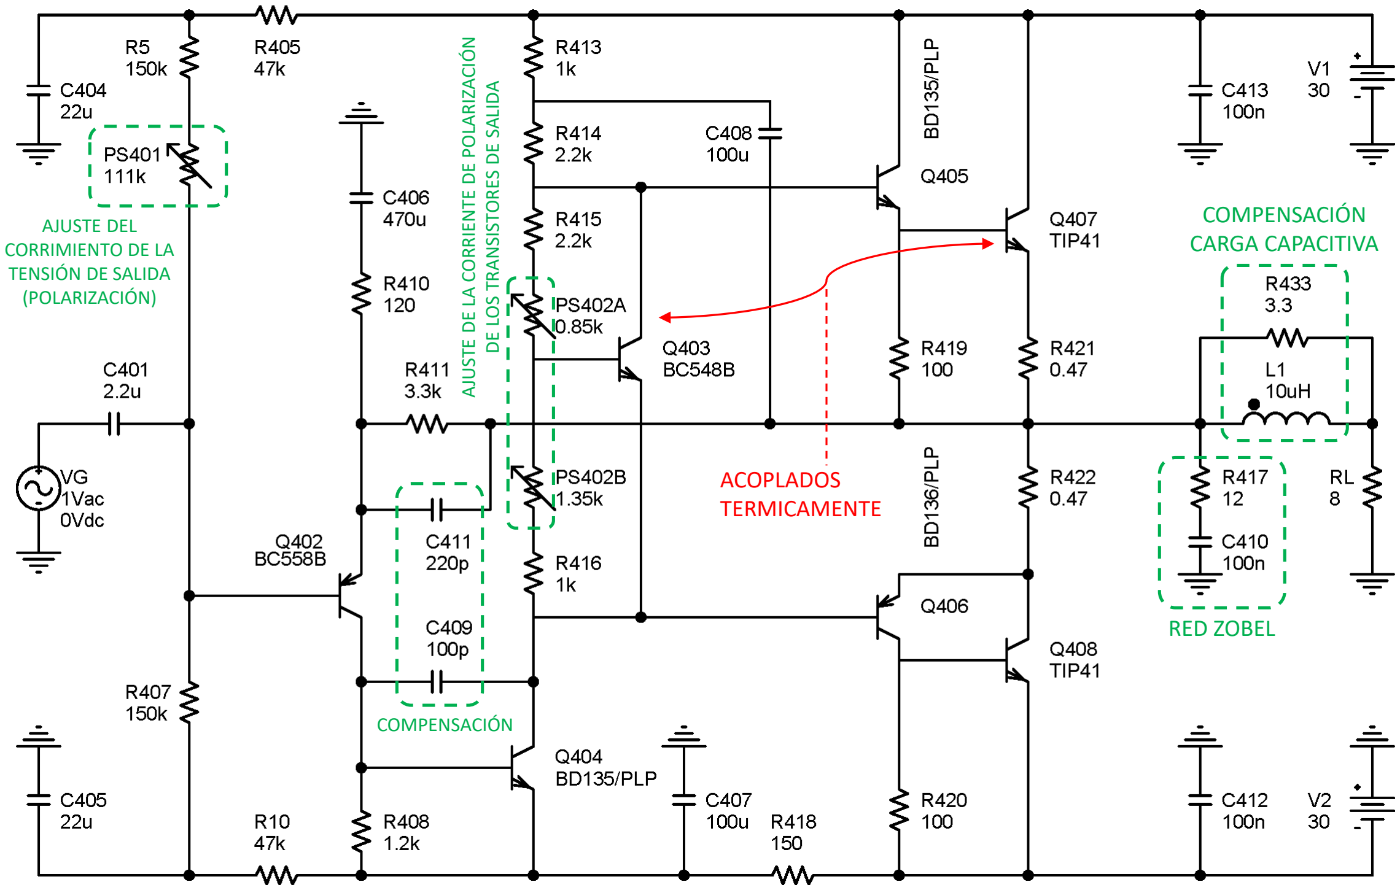
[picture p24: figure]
ACOPLADOS TERMICAMENTE; RED ZOBEL; COMPENSACIÓN; AJUSTE DEL CORRIMIENTO DE LA TENSIÓN DE SALIDA (POLARIZACIÓN); AJUSTE DE LA CORRIENTE DE POLARIZACIÓN; DE LOS TRANSISTORES DE SALIDA; COMPENSACIÓN CARGA CAPACITIVA

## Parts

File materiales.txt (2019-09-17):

bc557b x 10
bc547b x 10
R 68 *
R 100 *
R 390 + R 10
R 2.2k *
R 8.2k + R 1.5k
R 10k *
C 47u *
para compensacion
	C 100p
	C 1n
	C 10n
	C 100n
	C 1u

20/06

resistencias de emisor de fte corriente, 100
resistencias de realimentacion METALFILM, 680 y 27, y 2.2k y 82 (p/usar la de 2.2k del douglas self, da un poco mas de ganancia, 27,8 a la salida)
470 y 12k, xq el sumador+vas no funciona con las otras... WTF
resistencia de 10 para reemplazar la quemada del vas, de 47 y 68 para las ftes de corriente
de 100k para la carga del vas para medir

carbon
	R 100 x 5
	R 47 x 5
	R 68 x 5
	R 100k x 5
metalfilm
	R 680 x 5
	R 27 x 5
	R 2.2k x 5
	R 82 x 5
	R 470 x 5
	R 12k x5
jumper x 10
cable unipolar, 0,5 mts rojo, negro y marron
bornera x 3 para placa experimental

transistores de potencia

en la pagina de microelectronica aparecen
2SC5200 codigo nuevo, 2SC3281 codigo viejo que aparece en el douglas self (npn de salida)
2SA1943 codigo nuevo, 2SA1302 codigo viejo que aparece en el douglas self (pnp de salida)
mje340, mje350, los drivers

24/06

cantidades minimas

MPSA06 x 4
MPSA56 x 5
R carbon
	10 x 1
	47 x 1
	68 x 3
	100 x 2
	2.2k x 3
	10k x 2
	100k x 1
R metalfilm
	12k x 2
	470 x 1
C 100p x 1
C 47u x 2
C 1000u x 1
tira de pines para jumpers
bornera

02/07
MPSA06 x 4 (gm electrónica)
MPSA56 x 5 (gm electrónica)
mje340 x 3
mje350 x 2
2sc3281 x 2 (microelectrónica)
2sa1302 x 2 (microelectrónica)
LM385Z1.2D x 2 (gm electrónica, es el que viene en encapsulado smd)
1N4148SMD x 2
1N5822 x 2 (microelectrónica)

R

0,2 x 2 (1 W)
10 x 2
47 x 1
68 x 2
100 x 2
200 x 1
470 x 1 (1%)
1.2k x 1
2.2k x 4
3.3k x 1
12k x 2 (1%)

C

10 u poliester
1000 u
100 p
22 n
47 u x 5

17/09

SMD
C 47u
R 10k
R 2k2

potenciometro 200 ohm

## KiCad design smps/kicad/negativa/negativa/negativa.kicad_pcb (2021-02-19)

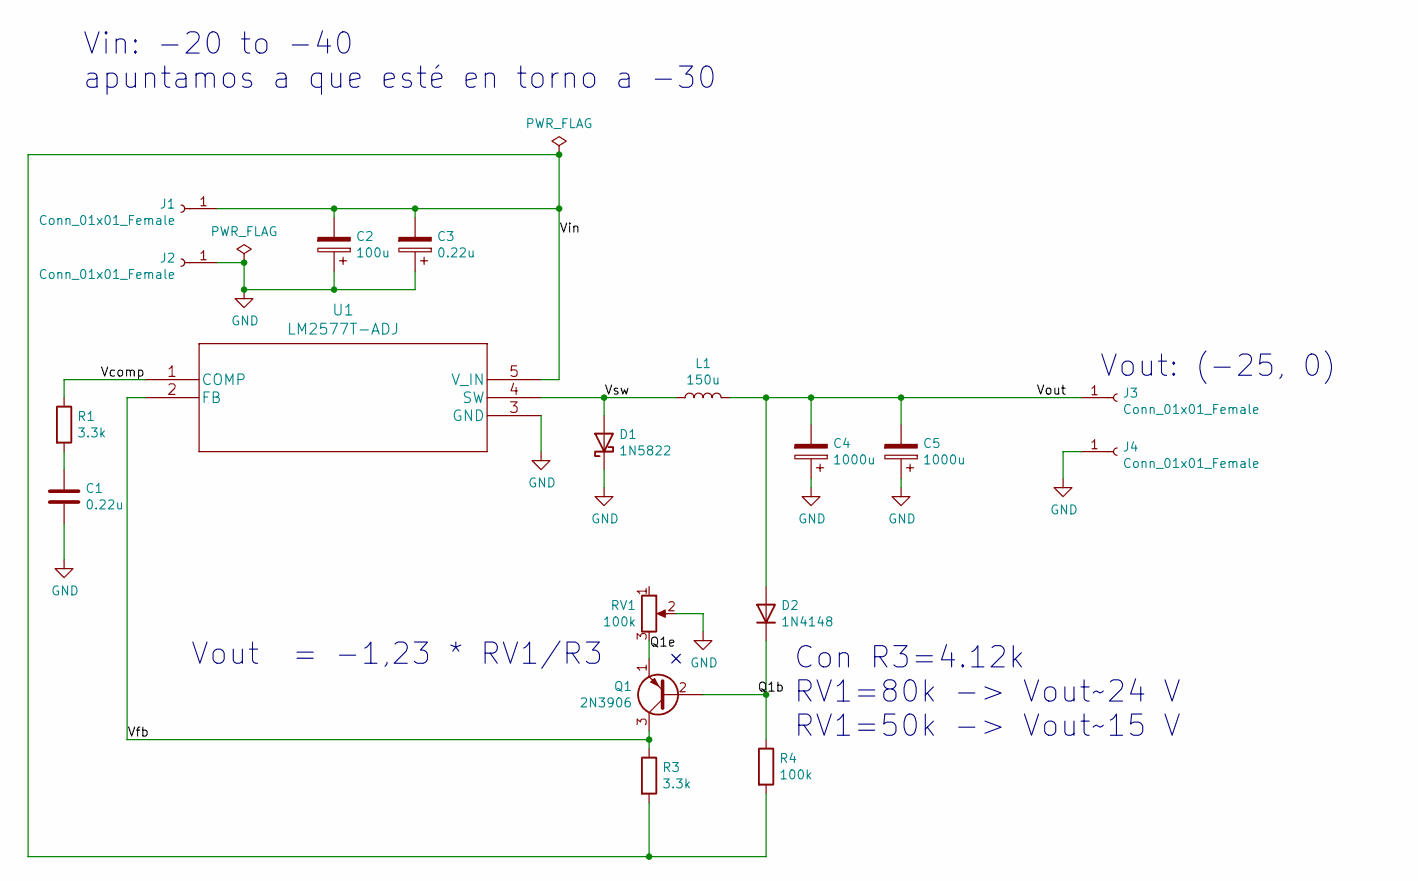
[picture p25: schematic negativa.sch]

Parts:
C1, C3: 0.22u; C_1206_3216Metric_Pad1.33x1.80mm_HandSolder
C2: 100u; CP_Radial_D8.0mm_P3.50mm
C4, C5: 1000u; CP_Radial_D16.0mm_P7.50mm
D1: 1N5822; D_DO-201AD_P15.24mm_Horizontal
D2: 1N4148; D_DO-35_SOD27_P7.62mm_Horizontal
J1, J2, J3, J4: Conn_01x01_Female; Banana_Jack_1Pin
L1: 150u; L_Toroid_Vertical_L31.8mm_W15.9mm_P13.50mm_Bourns_5700
Q1: 2N3906; TO-92_Inline
R1, R3: 3.3k; R_1206_3216Metric_Pad1.30x1.75mm_HandSolder
R4: 100k; R_1206_3216Metric_Pad1.30x1.75mm_HandSolder
RV1: 100k; Potentiometer_Bourns_3296W_Vertical
U1: LM2577T-ADJ

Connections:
/Q1b: D2.1 (K), Q1.2 (B), R4.1
/Q1e: Q1.1 (E), RV1.3
/Vcomp: R1.1, U1.1 (COMP)
/Vfb: Q1.3 (C), R3.1, U1.2 (FB)
/Vin: C2.2, C3.2, J1.1, R3.2, R4.2, U1.5 (V_IN)
/Vout: C4.2, C5.2, D2.2 (A), J3.1, L1.2
/Vsw: D1.2 (A), L1.1, U1.4 (SW)
GND: C1.2, C2.1, C3.1, C4.1, C5.1, D1.1 (K), J2.1, J4.1, RV1.2, U1.3 (GND)
unnamed: C1.1, R1.2

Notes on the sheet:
Vin: -20 to -40 apuntamos a que esté en torno a -30
Vout: (-25, 0)
Vout = -1,23 * RV1/R3
Con R3=4.12k RV1=80k -> Vout~~24 V RV1=50k -> Vout~~15 V

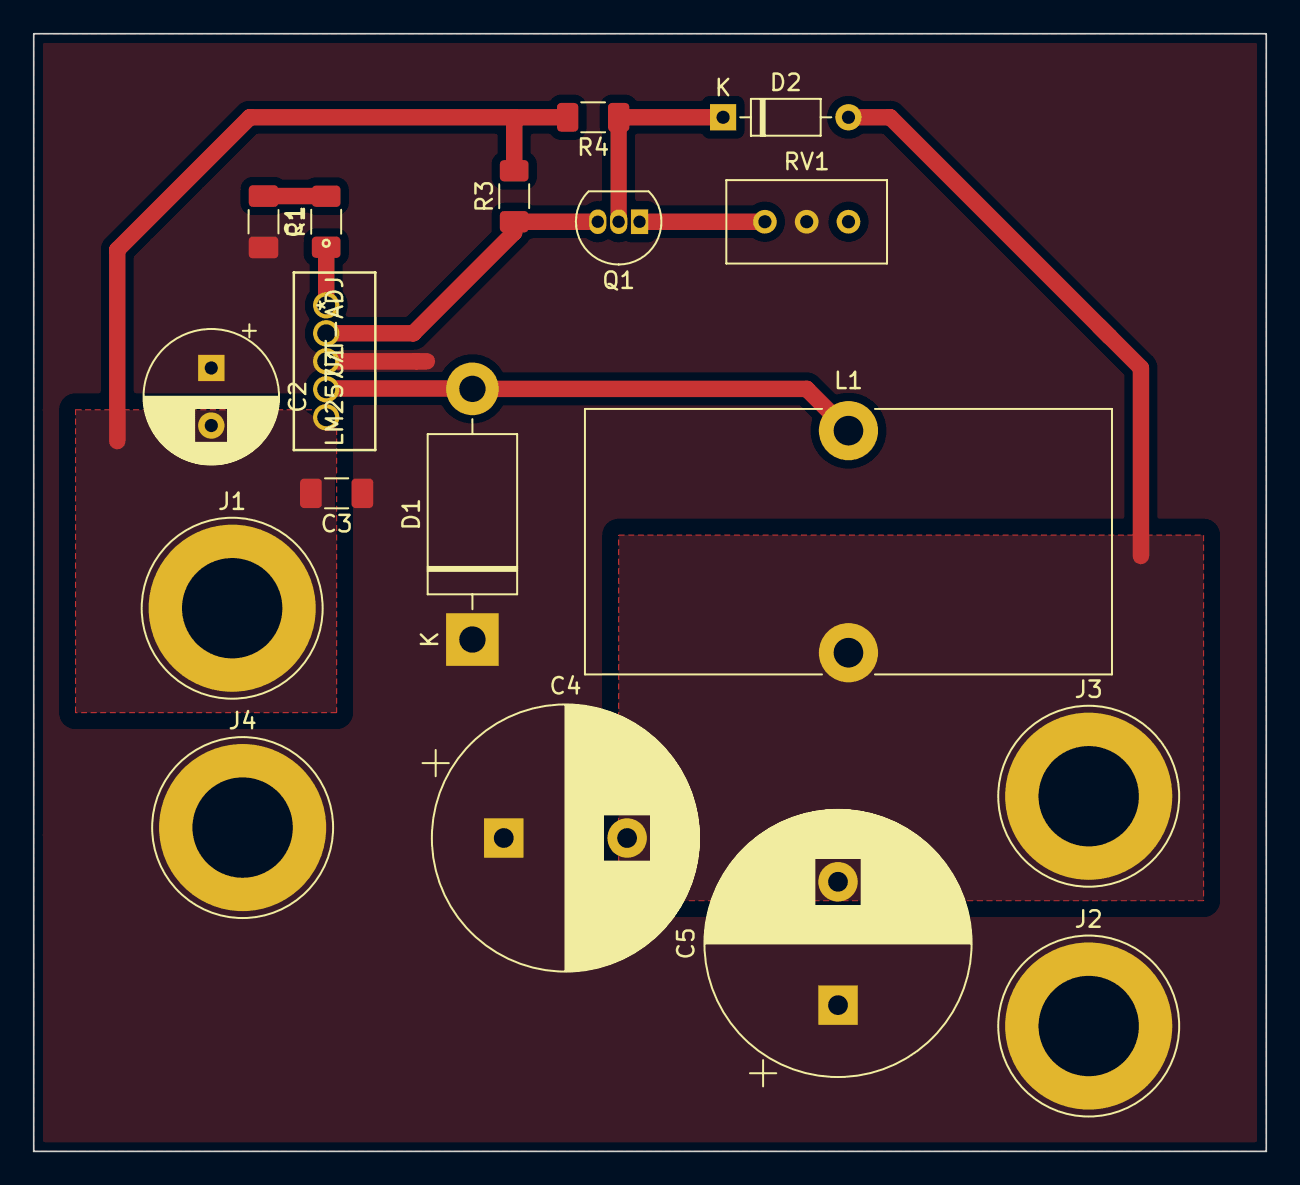
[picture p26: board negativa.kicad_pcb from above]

Board: 2 copper layers, 74.9 x 67.9 mm, 18 parts (0 on the bottom side), 9 nets.

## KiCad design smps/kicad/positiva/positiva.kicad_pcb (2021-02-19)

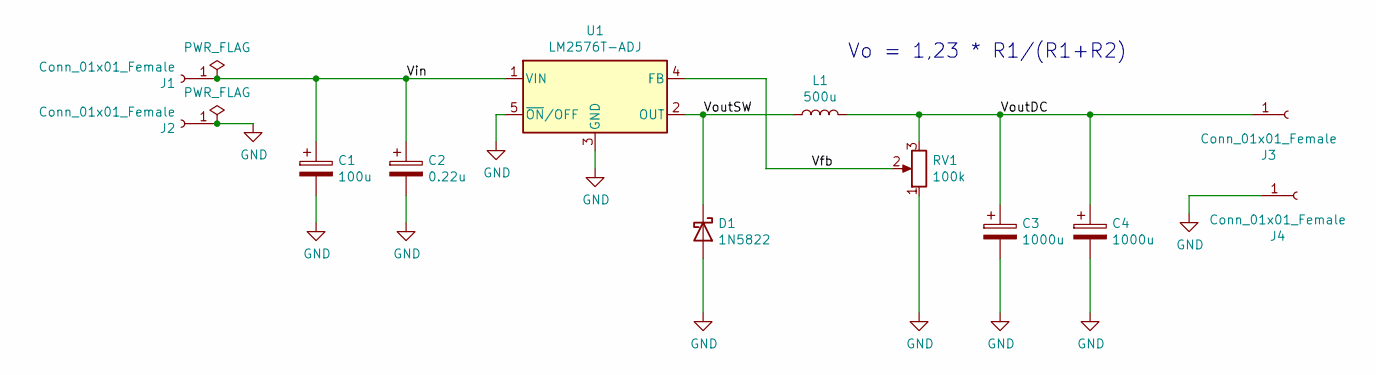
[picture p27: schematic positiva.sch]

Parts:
C1: 100u; CP_Radial_D8.0mm_P3.50mm
C2: 0.22u; C_1206_3216Metric_Pad1.33x1.80mm_HandSolder
C3, C4: 1000u; CP_Radial_D16.0mm_P7.50mm
D1: 1N5822; D_DO-201AD_P15.24mm_Horizontal
J1, J2, J3, J4: Conn_01x01_Female; Banana_Jack_1Pin
L1: 500u; L_Toroid_Vertical_L31.8mm_W15.9mm_P13.50mm_Bourns_5700
RV1: 100k; Potentiometer_Bourns_3296W_Vertical
U1: LM2576T-ADJ; TO-220-5_Vertical

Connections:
/Vfb: RV1.2, U1.4 (FB)
/Vin: C1.1, C2.1, J1.1, U1.1 (VIN)
/VoutDC: C3.1, C4.1, J3.1, L1.2, RV1.3
/VoutSW: D1.1 (K), L1.1, U1.2 (OUT)
GND: C1.2, C2.2, C3.2, C4.2, D1.2 (A), J2.1, J4.1, RV1.1, U1.3 (GND), U1.5 (~ON~/OFF)

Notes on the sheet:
Vo = 1,23 * R1/(R1+R2)

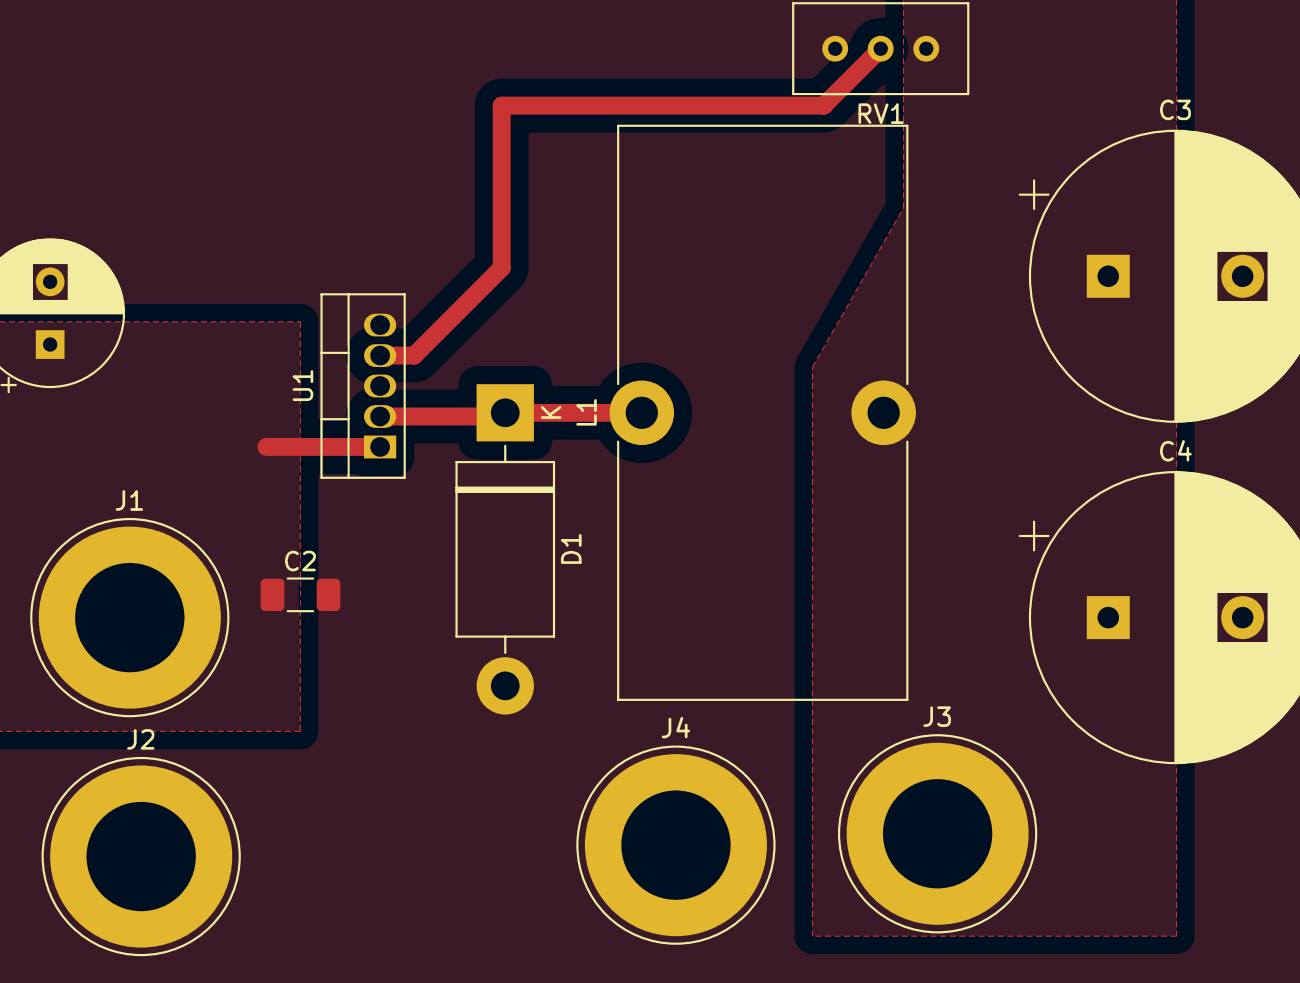
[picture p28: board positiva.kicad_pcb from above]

Board: 2 copper layers, 12 parts (0 on the bottom side), 5 nets.

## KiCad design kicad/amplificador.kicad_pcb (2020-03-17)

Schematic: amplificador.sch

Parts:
C1: 10u; C_Disc_D10.0mm_W2.5mm_P5.00mm
C2, C4: 47u; CP_Elec_3x5.3
C3: 1000u; CP_Radial_D7.5mm_P2.50mm
C5: 100p; CP_Elec_3x5.3
C6: 22n; CP_Elec_3x5.3
C7, C8: 1u; CP_Radial_D5.0mm_P2.00mm
D3, D4: 1N4148; D_DO-35_SOD27_P7.62mm_Horizontal
D5, D6: 1N5822; D_DO-201AD_P15.24mm_Horizontal
J1, J7, J8, J14, J16, J17, J21, J22, J23, J24: Screw_Terminal_01x01; PinHeader_1x01_P2.54mm_Vertical
J2, J3, J4, J5, J6, J9, J10, J11, J12, J13, J15, J18, J19, J20: Conn_01x01_Male; PinHeader_1x01_P2.54mm_Vertical
JP1, JP2, JP3, JP4: Jumper_NO_Small; PinHeader_1x02_P2.54mm_Vertical
Q1, Q3, Q5, Q6, Q8: MPSA92; TO-92_Inline
Q2, Q4, Q7, Q10: MPSA42; TO-92_Inline
Q9, Q11, Q13: BD135; TO-126-3_Vertical
Q12, Q14: BD136; TO-126-3_Vertical
Q15, Q16: 2SD1047; TO-3PB-3_Vertical
Q17, Q18: 2SB817; TO-3PB-3_Vertical
R1, R11: 12k; R_0805_2012Metric_Pad1.15x1.40mm_HandSolder
R2, R6, R14: 68; R_0805_2012Metric_Pad1.15x1.40mm_HandSolder
R3, R4, R5, R19, R20, R21, R22: 100; R_0805_2012Metric_Pad1.15x1.40mm_HandSolder
R7, R12, R13: 2.2k; R_0805_2012Metric_Pad1.15x1.40mm_HandSolder
R8: 470; R_0805_2012Metric_Pad1.15x1.40mm_HandSolder
R9, R10: 10k; R_0805_2012Metric_Pad1.15x1.40mm_HandSolder
R15, R18: 10; R_0805_2012Metric_Pad1.15x1.40mm_HandSolder
R16: 3.3k; R_0805_2012Metric_Pad1.15x1.40mm_HandSolder
R17: 1.2k; R_0805_2012Metric_Pad1.15x1.40mm_HandSolder
R23: 220; R_0805_2012Metric_Pad1.15x1.40mm_HandSolder
R24, R25: 0.4; R_Axial_DIN0414_L11.9mm_D4.5mm_P25.40mm_Horizontal
R26: 200; R_Box_L8.4mm_W2.5mm_P5.08mm
U1, U2: LM385D-1.2; SOIC-8_3.9x4.9mm_P1.27mm

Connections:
/+Vcc: C2.2, C4.2, C7.2, J8.1, Q6.1, Q11.2 (C), Q13.2 (C), Q15.2, R4.2, R14.2
/-Vcc: C8.1, J7.1, Q12.2 (C), Q14.2 (C), Q18.2, R2.1, R6.2, R12.2, R15.2
/Io1: J19.1, Q3.3, R3.1, R5.2
/Io2: D3.2, JP4.2, Q8.3, U1.4 (A)
/Vi: C1.2, J1.1
/Vi_buffer: C5.2, JP3.2, Q7.2
/Vi_vas: Q7.1, Q10.2, R12.1
/Via: C1.1, J15.1, Q1.2, R1.2
/Vo: J14.1, JP2.2, R24.2, R25.1
/Vo_sumador: JP3.1, Q1.3, Q2.3
/Vo_vas: C5.1, D4.1, J18.1, Q10.3, U2.8 (K)
GND: C3.2, C7.1, C8.2, J21.1, J22.1, J23.1, J24.1, JP1.2, JP4.1, Q7.3, R1.1, R10.2
unnamed: C2.1, Q3.2, R7.1
unnamed: C3.1, R8.1
unnamed: C4.1, R9.2, R10.1
unnamed: C6.1, Q9.1 (E), R20.2, R26.2, U2.4 (A)
unnamed: C6.2, Q9.2 (C), R18.2, R19.2
unnamed: D3.1, Q11.3 (B)
unnamed: D4.2, Q12.3 (B)
unnamed: D5.1 (K), J16.1
unnamed: D5.2 (A), Q17.2, Q18.3, R22.1
unnamed: D6.1 (K), Q15.3, Q16.2, R21.2
unnamed: D6.2 (A), J17.1
unnamed: J2.1, Q1.1, R3.2
unnamed: J3.1, Q2.1, R2.2
unnamed: J4.1, Q3.1, R4.1
unnamed: J5.1, Q5.1, R5.1
unnamed: J6.1, Q4.1, R6.1
unnamed: J9.1, Q8.1, R13.1, R14.1
unnamed: J10.1, Q13.3 (B), R19.1
unnamed: J11.1, Q14.3 (B), R20.1
unnamed: J12.1, Q13.1 (E), Q16.1, R23.1
unnamed: J13.1, Q14.1 (E), Q17.1, R23.2
unnamed: J20.1, Q5.2, R8.2, R11.2
unnamed: JP1.1, JP2.1, R11.1
unnamed: Q2.2, Q4.2, Q4.3, Q5.3
unnamed: Q6.2, R13.2
unnamed: Q6.3, Q8.2, R7.2, R9.1
unnamed: Q9.3 (B), R16.2, R17.1
unnamed: Q10.1, R15.1
unnamed: Q11.1 (E), Q15.1, R21.1
unnamed: Q12.1 (E), Q18.1, R22.2
unnamed: Q16.3, R24.1
unnamed: Q17.3, R25.2
unnamed: R16.1, R18.1, U1.8 (K)
unnamed: R17.2, R26.1

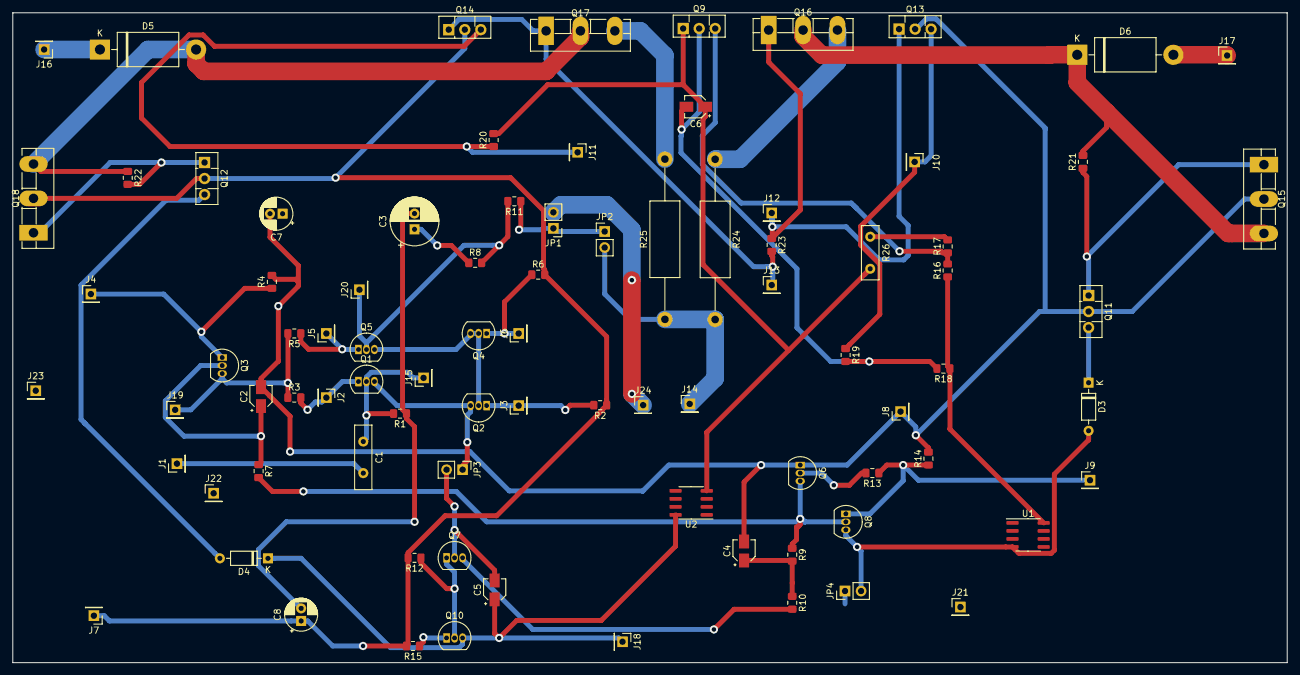
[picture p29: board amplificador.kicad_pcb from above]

Board: 2 copper layers, 202.0 x 103.0 mm, 86 parts (0 on the bottom side), 46 nets.

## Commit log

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2019-06-04 se actualiza el circuito total al realimentado con el sumador pero sin el seguidor de salida, queda ajustar para que de excursion simetrica
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2019-06-05 se incluyo la fuente de corriente del douglas self en el circuito total, se elimino la realimentacion de la fte espejo del sumador y se incremento la del par diferencial, amplfifica bien sin recorte 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
2019-06-10 fuente de salida con polarización, tiene 4 de continua a la salida, recorta
2019-06-11 se agrega la etapa de salida, polarizada y con generadores, y el circuito total. el de salida con generadores da bien salvo por una atenuacion, tiene thd de 0.7, el que esta polarizado da continua a 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
2019-06-17 circuito total con transistores de potencia a la salida y se reemplazan los zener por diodos comunes (menos caida)
2019-06-17 agregamos los archivos kicad
    [amplificador.kicad_pcb, amplificador.sch]
2019-06-17 esquematico de kicad completo, faltan las fuentes interiores de la etapa de salida nada mas
    [amplificador.sch]
2019-06-18 Seleccionado de footprints para resistores smd
    [amplificador.sch]
2019-06-20 Inicio del ruteo
    [amplificador.sch]
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2019-06-20 agregamos las datasheets de los bc557 y bc547
    [amplificador.sch]
2019-06-21 cambiamos las R de realimentacion por valores comerciales, la de la fte de corriente, las de emisor de la carga activa, cargamos los modelos de varios transistores de potencia
2019-06-21 pcb Kicad actualizado
    [amplificador.kicad_pcb]
2019-06-23 Primer ruteo
    [amplificador.kicad_pcb]
2019-06-23 simulacion cumpliendo especificaciones, usa todos los transistores del douglas self, agregamos datasheets y borramos modelos viejos que no se usaban
2019-06-23 arreglamos la simulacion que no se habia mergeado
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2019-06-26 Actualización del pcb
    Se acercaró el multiplicador de vbe a los transistores de potencia por acoplamiento térmico. Se dejó lugar para montarlos sobre un disipador.
    [amplificador.kicad_pcb]
2019-06-27 modificamos el valor del capacitor de acople y mandamos el capacitor de 1000u a V- en vez de tierra, actualizamos todos los circuitos para que tengan la realimentacion correcta y consistente
2019-06-27 cambios al pcb
    [amplificador.sch]
2019-06-28 Ruteo del esquemático modificado
    Capacitor a -30V, encapsulados finales, capacitor de entrada de poliéster.
    [amplificador.kicad_pcb, amplificador.sch]
2019-06-28 viaje en el tiempo... el commit anterior esta roto
    [amplificador.kicad_pcb, amplificador.sch]
2019-06-29 Final de clase viernes 28 de junio
    [amplificador.kicad_pcb, amplificador.sch]
2019-07-02 carpeta kicad con esquematico con todos los encapsulados correctos, jumpers, pines de alimentacion y medicon. pcb a medio hacer
    [amplificador.kicad_pcb]
2019-07-02 cambios en los jumpers, ruteo avanzado
    [amplificador.kicad_pcb, amplificador.sch]
2019-07-02 actualizamos lista de materiales a la final, agregamos recordatorio de capa de bypass en las notas de kicad, reemplazamos el mpsa del multiplicador de vbe por un mje
2019-07-03 agregamos hojas de datos, cambiamos el esquematico un poco (footprints, sacamos algunos pines, agregamos capas de filtrado), el pcb esta dispuesto de la misma forma que el esquematico, queda optimiza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
    [amplificador.kicad_pcb, amplificador.sch]
2019-07-03 intento de optimización de pcb: seguramente haya que volver a la versión anterior y tirar una via para la realimentación...
2019-07-03 How many vias are too many vias?
    [amplificador.kicad_pcb]
2019-07-05 PCB DRC actualizado
    [amplificador.kicad_pcb, amplificador.sch]
2019-07-08 PCB versión 1.0
    Planos de alimentación, ancho de pistas y nuevos pines GND.
    [amplificador.kicad_pcb, amplificador.sch]
2019-07-13 Planos de masa separados por etapas
    [amplificador.kicad_pcb]
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2019-07-16 reemplazamos el q del mult del vbe x un mje, agregamos nombres a las nets e indicamos cuales son de potencia
    [amplificador.sch]
2019-07-27 Se cambio el footprint del multiplicador de vbe en el pcb
    [amplificador.kicad_pcb]
2019-08-05 configurado con un clearance de 0.32 mm
    [amplificador.kicad_pcb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]
2019-09-01 DRC arreglo - separación pista pad
    Problema a resolver: los transistores Q1 a Q10 (MPSA) tienen sus pad muy cercanos entre sí y no cumplen las reglas del LCI. ¿Hay que cambiar de transistores?
    [amplificador.kicad_pcb]
2019-09-01 Planos de masa agregados
    [amplificador.kicad_pcb]
2019-09-17 actualizamos lista de materiales y algunos valores del circuito que estaban mal
    [amplificador.kicad_pcb, amplificador.sch]
2019-10-29 el jumper JP4 estaba mal, tenía que ir a tierra, se actualizó el esquemático y el pcb. En el pcb se saco una via
    [amplificador.kicad_pcb, amplificador.sch]
2019-10-29 cambiamos resistencia de 200 por una de 220
    [amplificador.kicad_pcb, amplificador.sch]
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2019-12-19 agregamos los valores que se deberían medir sobre la simulación del punto de operación
2019-12-20 corregimos la conexió que faltaba en la fuente de corriente en el proyecto de kicad
    [amplificador.kicad_pcb]
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2020-02-04 Etapa VAS bien polarizada.
    [amplificador.kicad_pcb, amplificador.sch]
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2020-03-12 Arreglo de las pistas de tierra. Circuito sin carga en funcionamiento.
    Revisar transitorio al conectar carga.
2020-03-15 trabajo del 13/03
    [amplificador.kicad_pcb, amplificador.sch]
2020-03-17 trabajo del 16/03
    [amplificador.kicad_pcb, amplificador.sch]
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2020-11-10 varias cosas switching
    [positiva.kicad_pcb, positiva.sch]
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2021-02-03 layout de fuente switching positiva
    [positiva.kicad_pcb, positiva.sch]
2021-02-15 layout inicial fuente negativa
    [negativa.kicad_pcb, negativa.sch]
2021-02-16 varias cosas, layouts de fuentes terminados, calculo de componentes completo
    [negativa.kicad_pcb, negativa.sch, positiva.kicad_pcb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]
2021-02-19 last minute commit
    [negativa.kicad_pcb, negativa.sch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]
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

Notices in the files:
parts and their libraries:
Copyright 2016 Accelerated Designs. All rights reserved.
